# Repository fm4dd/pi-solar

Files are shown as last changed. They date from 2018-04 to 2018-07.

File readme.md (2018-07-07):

# Pi-Solar

Pi-Solar is a solar power generation project for the Raspberry Pi weather station <a href="https://github.com/fm4dd/pi-weather">Pi-Weather</a>, with the goal to achieve independent and longterm "off-the-grid" operation. This project documents the system design and the solar power generation monitoring software that watches over the electrical energy balance.

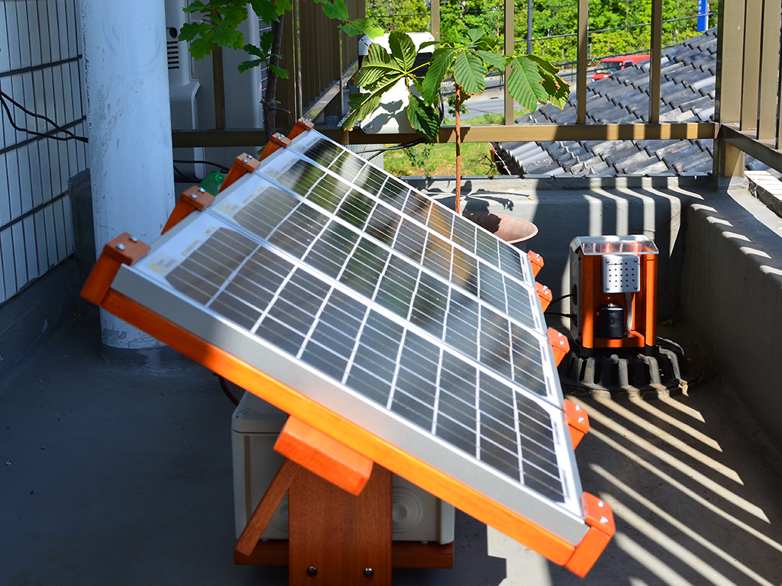
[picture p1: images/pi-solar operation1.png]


The solar power generator after construction, during the initial burn-in trials.

## Live Power Status

http://weather.fm4dd.com/pi-ws01/solar.php

## Design

The solar panel array has four 10W Autumn Technology AT-MA10A pv panels, connected via Victron BlueSolar MPPT 75/10 charge controller to a Yuasa NPH12-12 deep-cycle battery.  The solar panel array angle can be adjusted up to approx 48 degrees.

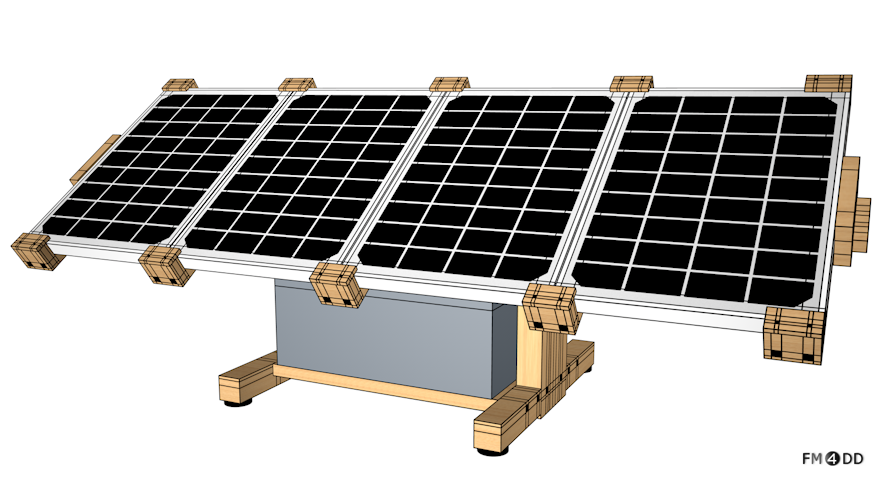
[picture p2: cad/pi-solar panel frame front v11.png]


Battery and charge controller are placed in a OBO T350 junction box enclosure below the panel array. There is space for a second battery to enhance the capacity and increase the bad weather safety margin. 

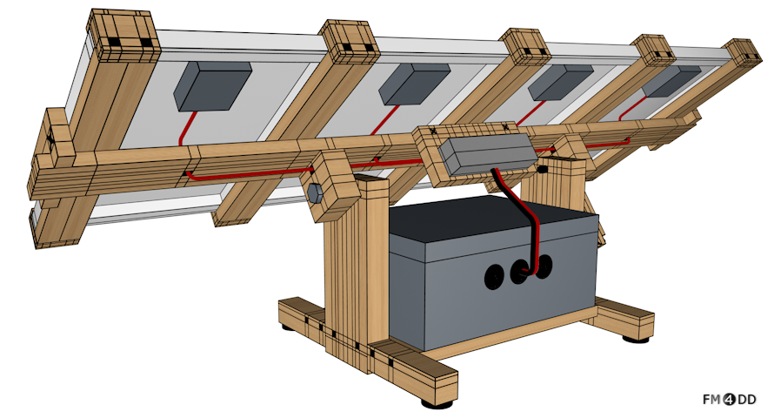
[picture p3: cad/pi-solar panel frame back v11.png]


## Charge Controller monitoring software

The charge controller selection zeroed in on Victron's BlueSolar and SmartSolar series. The selection criteria besides panel power match-up are compact size, ruggedness, and a data interface with a open specification. 

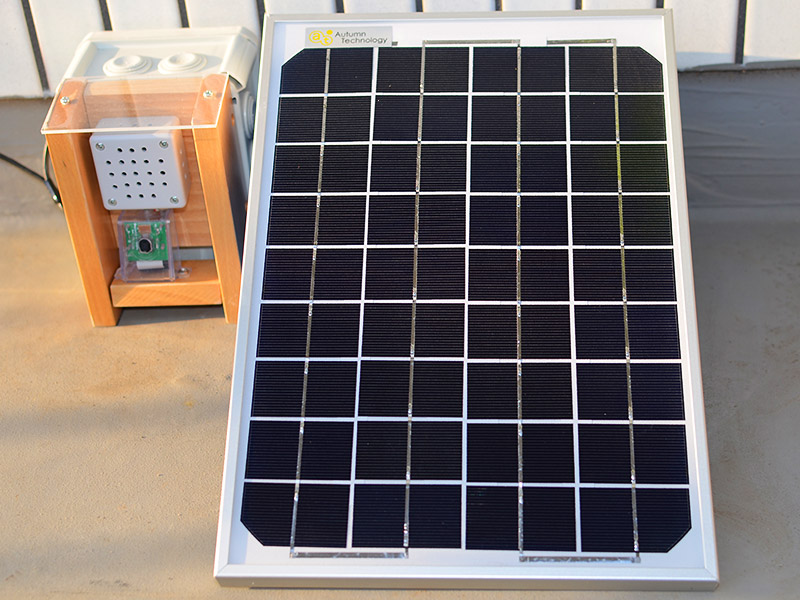
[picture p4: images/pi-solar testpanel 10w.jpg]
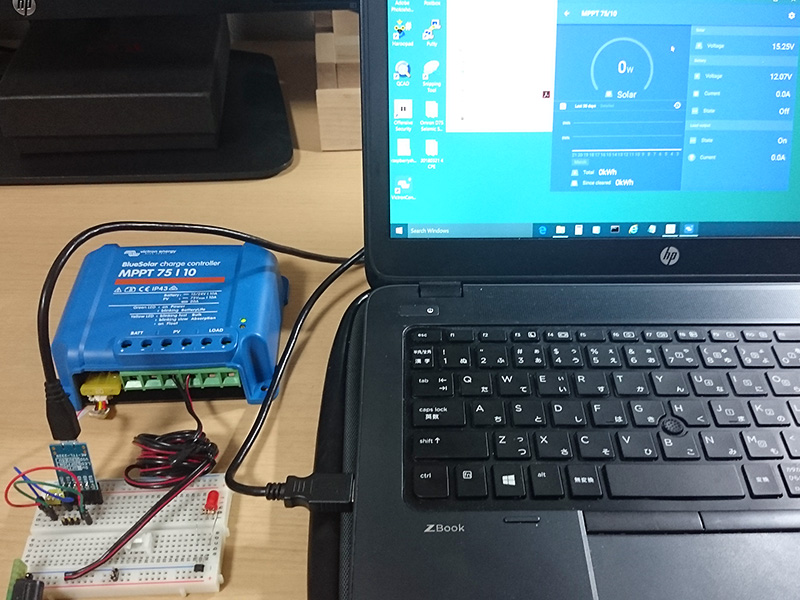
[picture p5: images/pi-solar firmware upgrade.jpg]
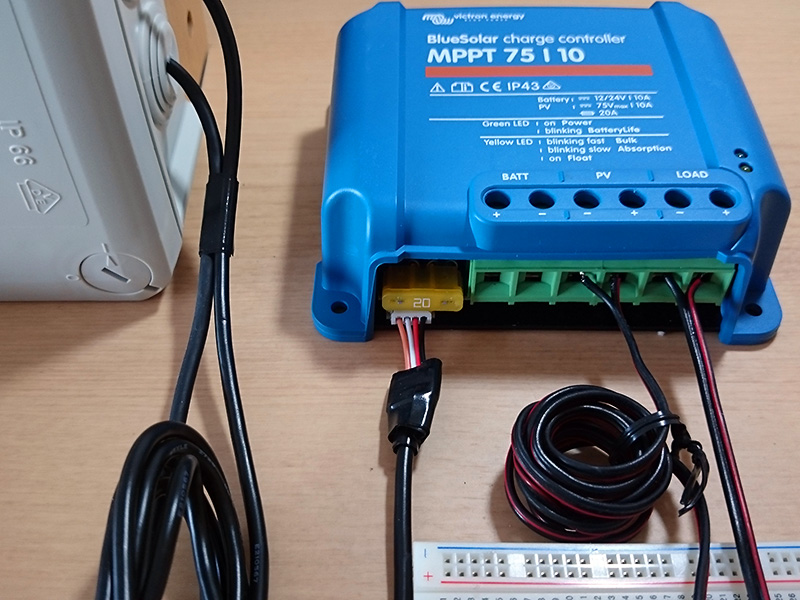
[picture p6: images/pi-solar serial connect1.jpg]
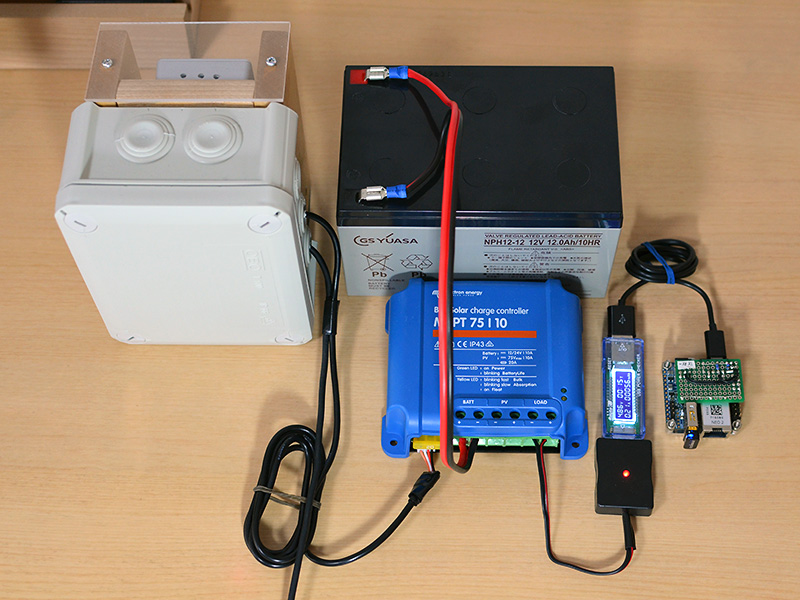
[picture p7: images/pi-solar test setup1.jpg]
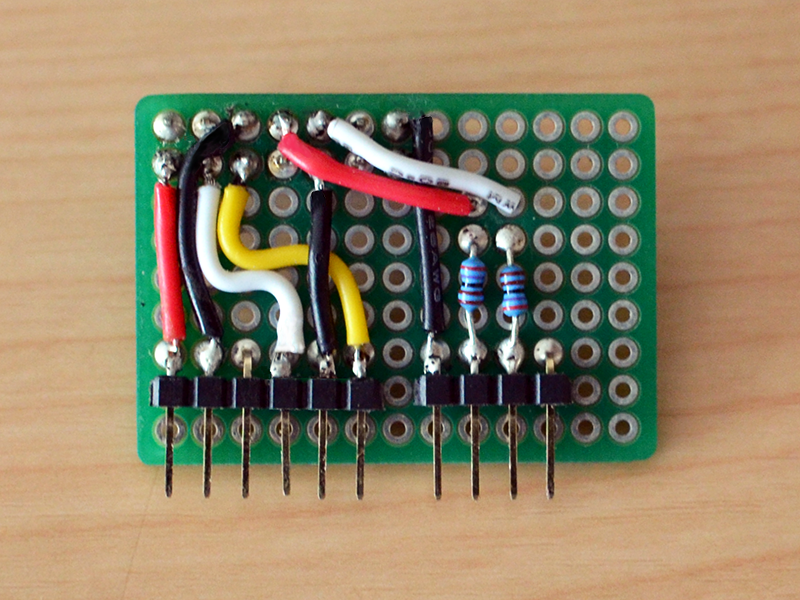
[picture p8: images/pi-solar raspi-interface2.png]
    

The serial line interfacing with a Raspberry Pi worked fine, using a small prototyping circuit board.  Initial software development was mostly done on a NanoPi Neo2 Raspberry clone. The monitoring software was written while powering the controller from a 12V wall plug adapter.  



Charging graph example, showing the panel voltage over 24 hours. The necessary software can be cloned from the <a href="code">code</a> directory.
 
## Solar Panel Array Frame

The <a href="cad">cad</a> directory has the hardware BOM and CAD drawings for panel frame manufacture, and lists the required components. Design goals for the frame are ruggedness, panel tilt adjustment, wood material, assembly/dissassembly options, and portable parts with a size not exceeding 60 cm length.

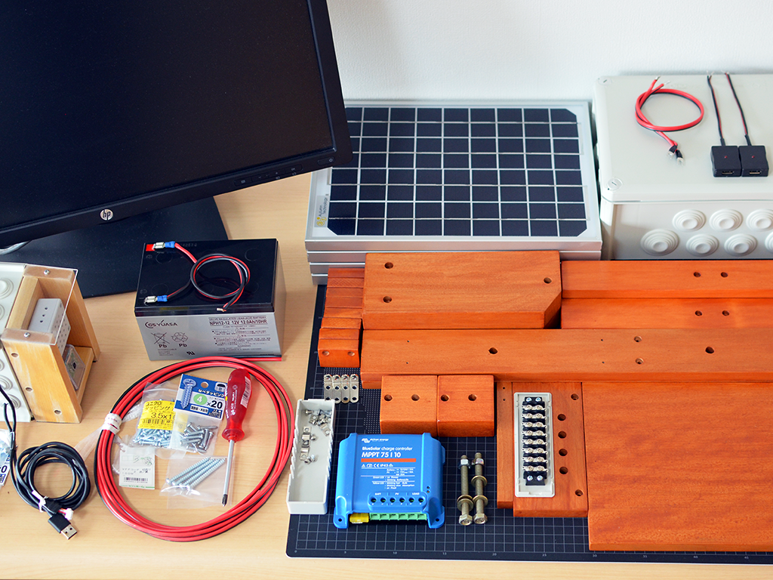
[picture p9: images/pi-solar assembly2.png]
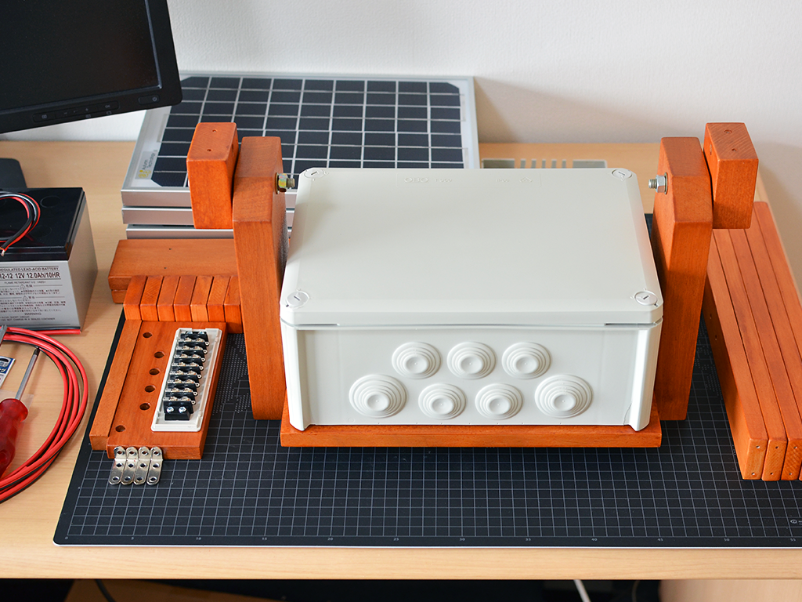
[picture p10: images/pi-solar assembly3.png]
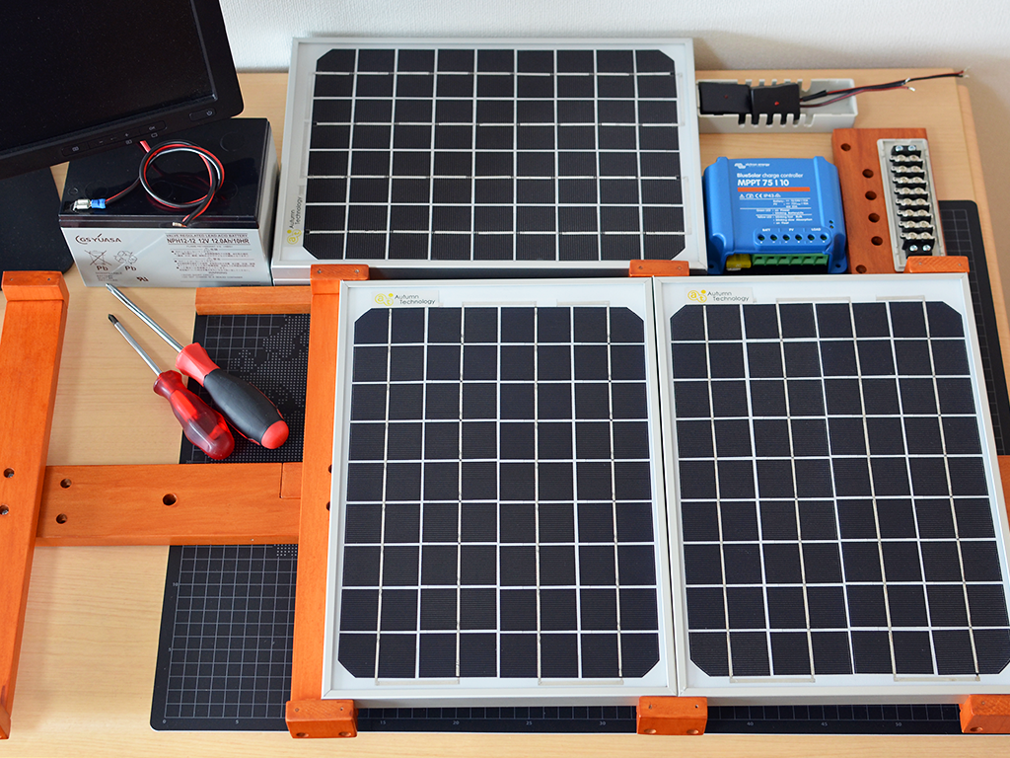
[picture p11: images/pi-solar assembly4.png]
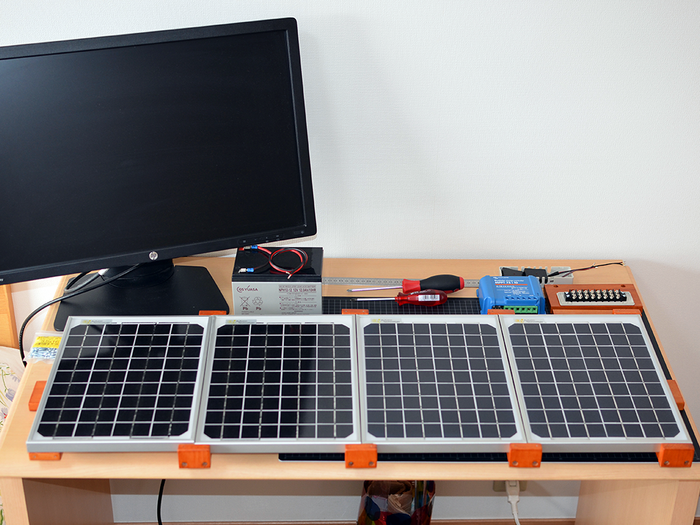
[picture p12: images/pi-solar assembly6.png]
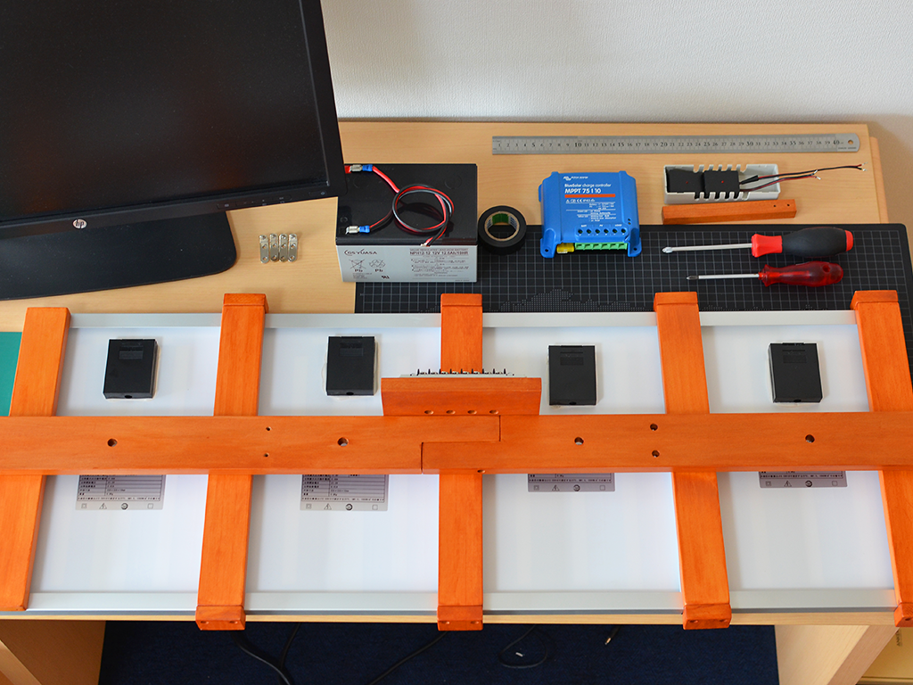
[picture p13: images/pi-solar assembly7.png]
    

Panel fitting and wire routing:

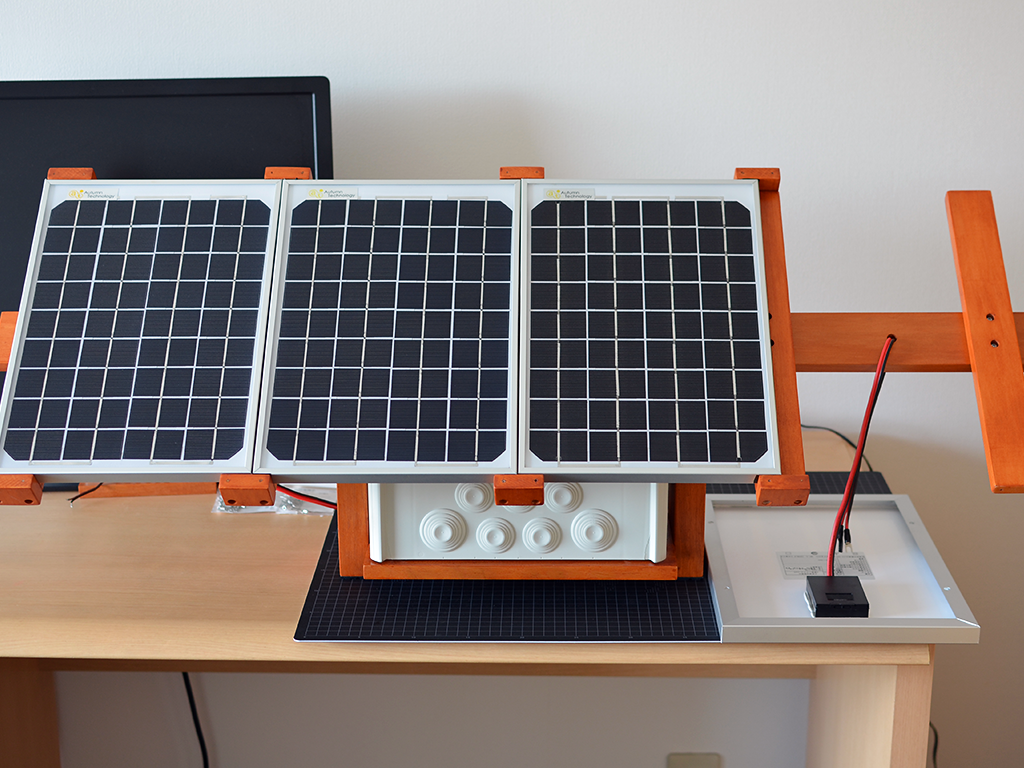
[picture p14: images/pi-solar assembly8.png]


The solar panel wiring has been upgraded to 2mm copper wire of equal length, and a 10A10 rectifier bypass diode has been installed.

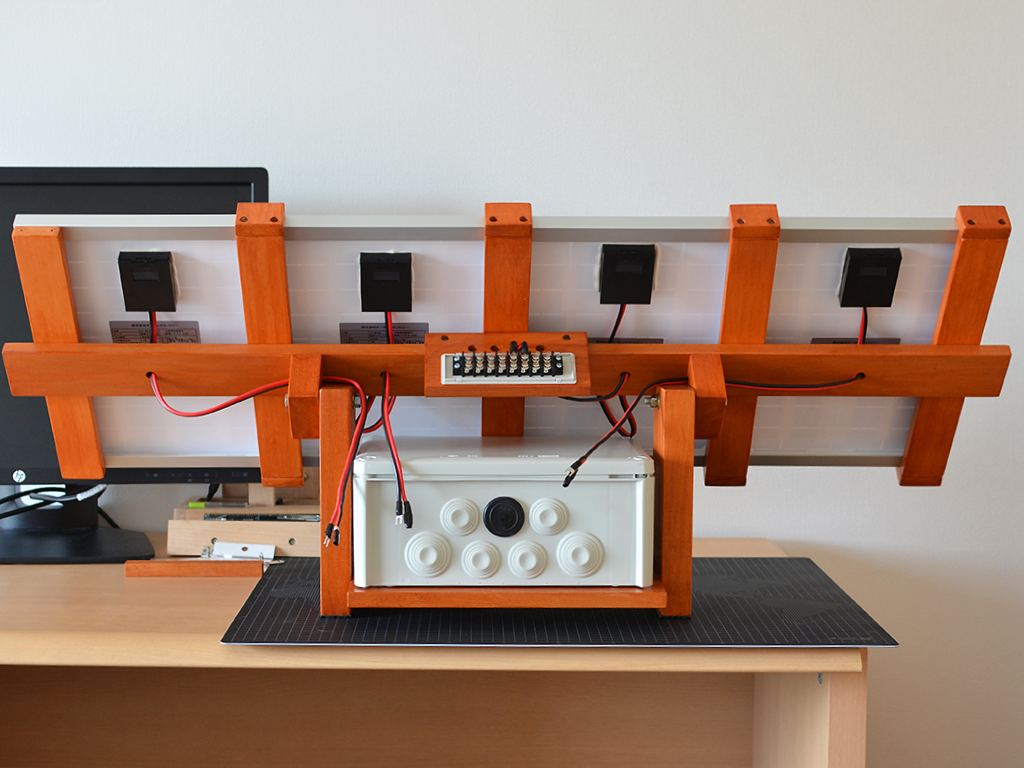
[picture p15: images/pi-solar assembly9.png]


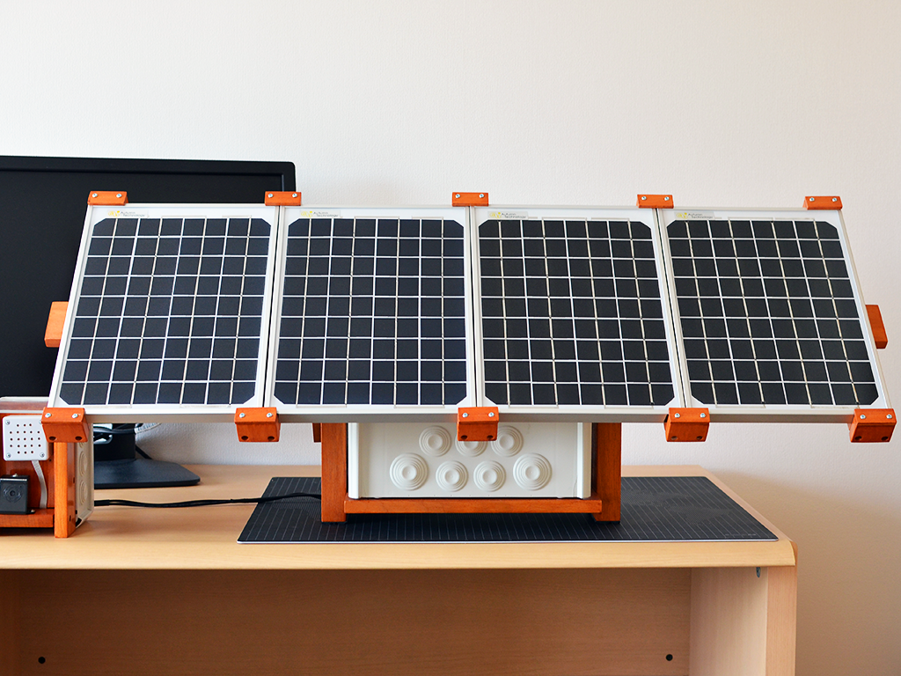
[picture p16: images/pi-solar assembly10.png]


The completed frame after assembly. The stand turned out to be insufficiently stable due to the panel weight with a high center of gravity. Four stabilizers (not pictured here) were added afterwards to sufficiently counter the weight and prevent tipping in high wind situations.

## Power observations

Initial power trials with three panels (30W) showed the need for greater power "buffer" even with a MPPT charger. Poor conditions such as bad weather and obstructive shading reduce the power generation to near zero, and need to be compensated with charging as fast as possible when conditions are right. The initial solar array frame design, envisioning three panels, was reworked to incorporate one more panel for a total of four.

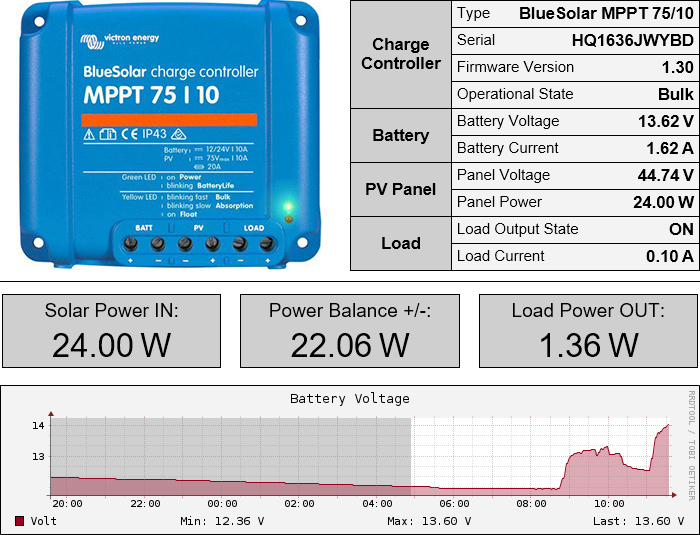
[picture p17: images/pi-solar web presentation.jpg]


3-Panel trials data collection. With panels arranged in series, achieving a higher voltage did not result in better perfomance.

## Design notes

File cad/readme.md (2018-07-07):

# Pi-Solar Design and Build Documentation

This folder contains documentation for the physical build  of a 40W mini solar power generation system. It includes CAD drawings, wiring schemas, bill of materials (BOM) and build pictures.

## PV Panels

Solar power generation comes from four 10W modules, Chinese-build panels from Autumn Technology, model number AT-MA10A.



|Electrical Data|Value |
|---|-|
|Maximum Power|10 W|
|Maximum Operating Voltage|17.5 V|
|Maximum Operating Current|0.57 A|
|Open Circuit Voltage|21.6 V|
|Short Circuit Current|0.62 A|
|Module Efficiency|19.5 %|

|Physical Data|Value|
|---|-|
|External Dimensions|235×335×18mm|
|Module Weight|0.9 Kg|

The panels are build from a string of 36 cell modules, using 2 different cell types: either Bosch, or JA-Solar. Depending on the module type, the panel characteristics are slightly different for operating voltage and current.

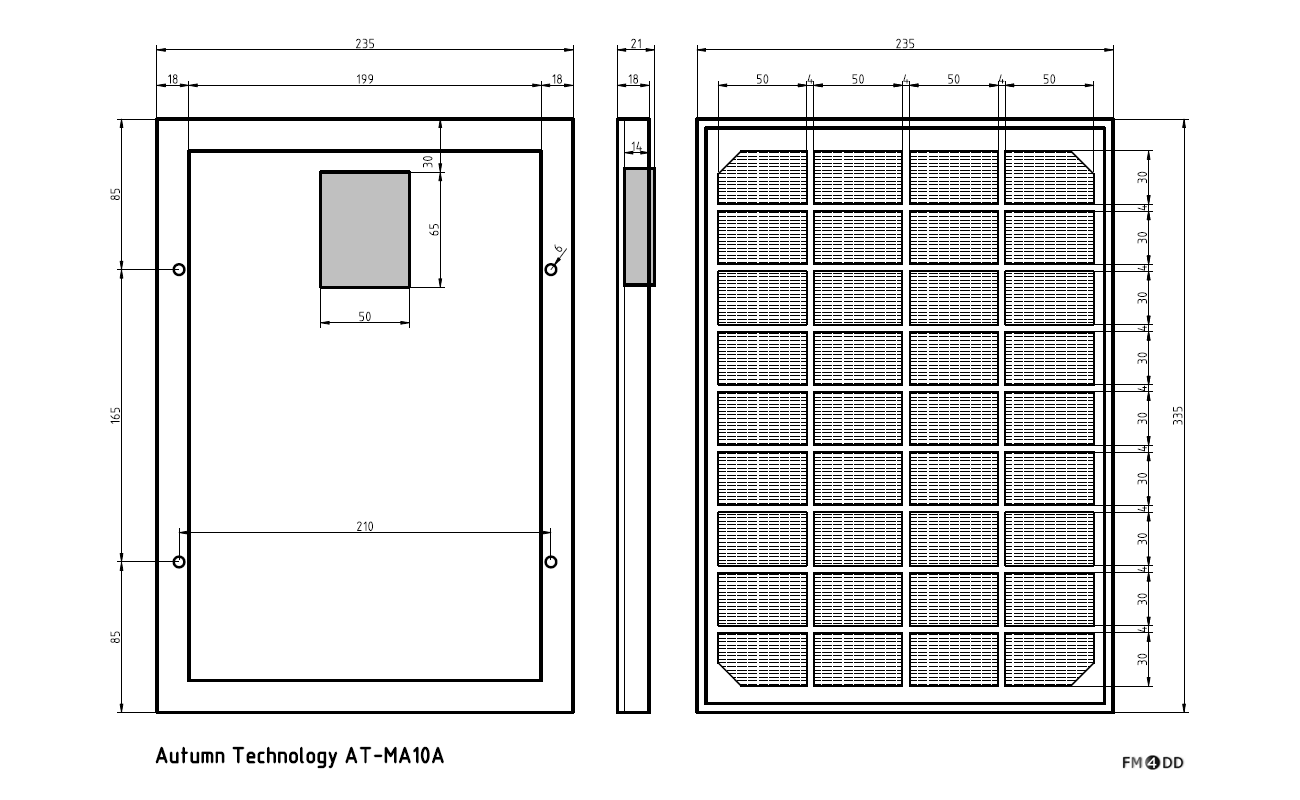
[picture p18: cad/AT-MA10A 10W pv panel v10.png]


##  PV panel carrier frame parts

The PV modules are installed on a carrier frame, which also holds the electrical components including cable terminal, deep-cycle battery, charge controller, and voltage converter. The PV panel holder is mounted with tilt angle adjustment.

###  Side pillars A-B

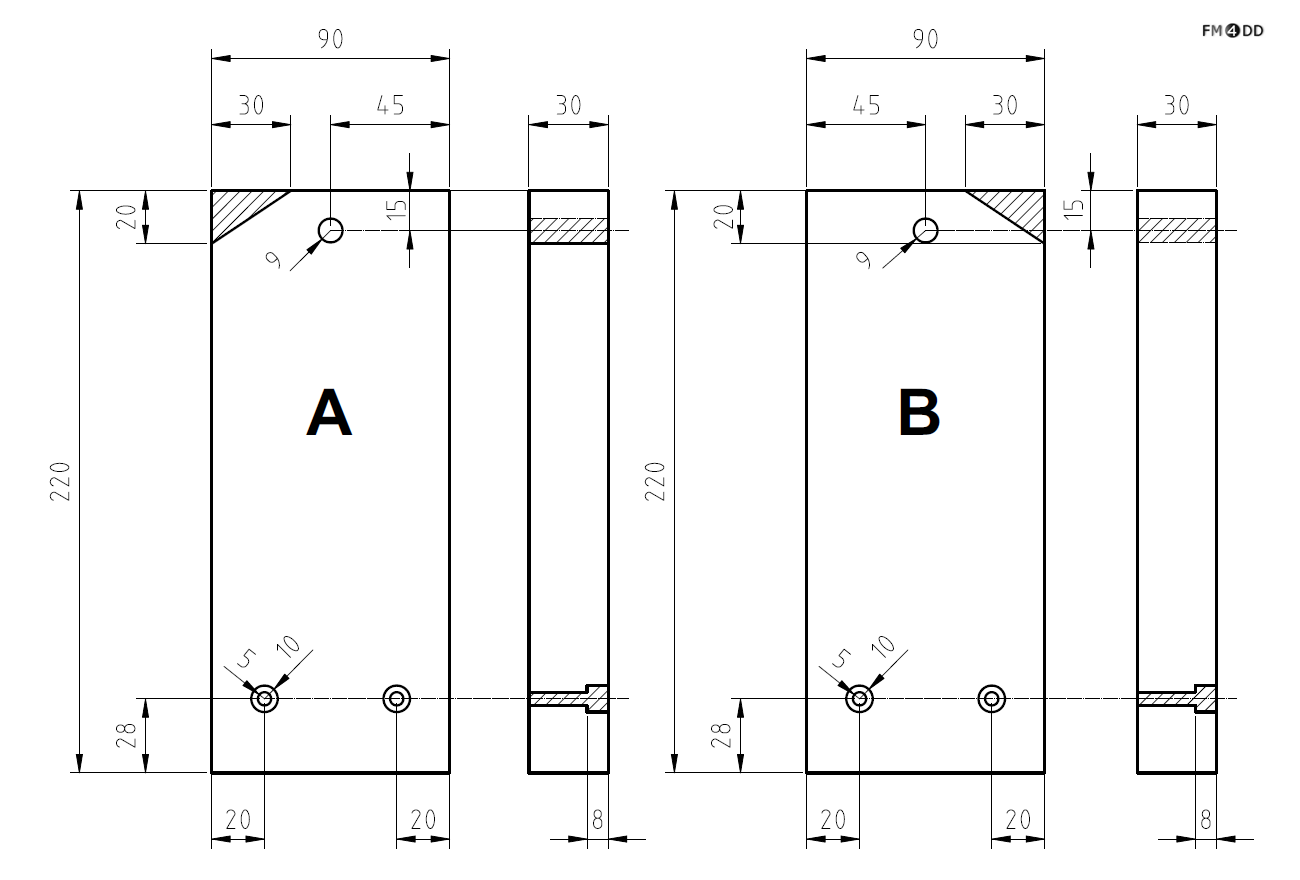
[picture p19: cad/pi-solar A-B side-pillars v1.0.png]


Side pillars A-B (left,right) fix a 300x200 panel 20mm above ground. The bottom panel holds the OBO T350 junction box containing electrical components.

###  Pivot Blocks C-D

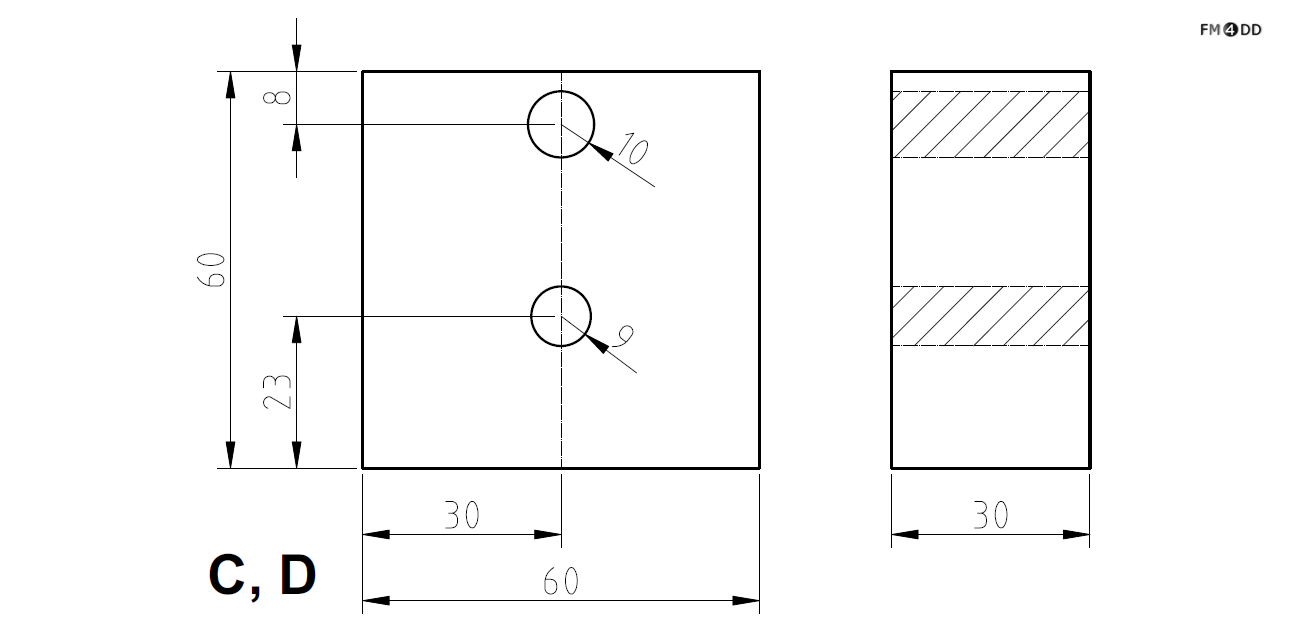
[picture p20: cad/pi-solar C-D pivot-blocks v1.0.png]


Pivot blocks attach the PV panel holder to the side pillars.

###  Main Bars E-F

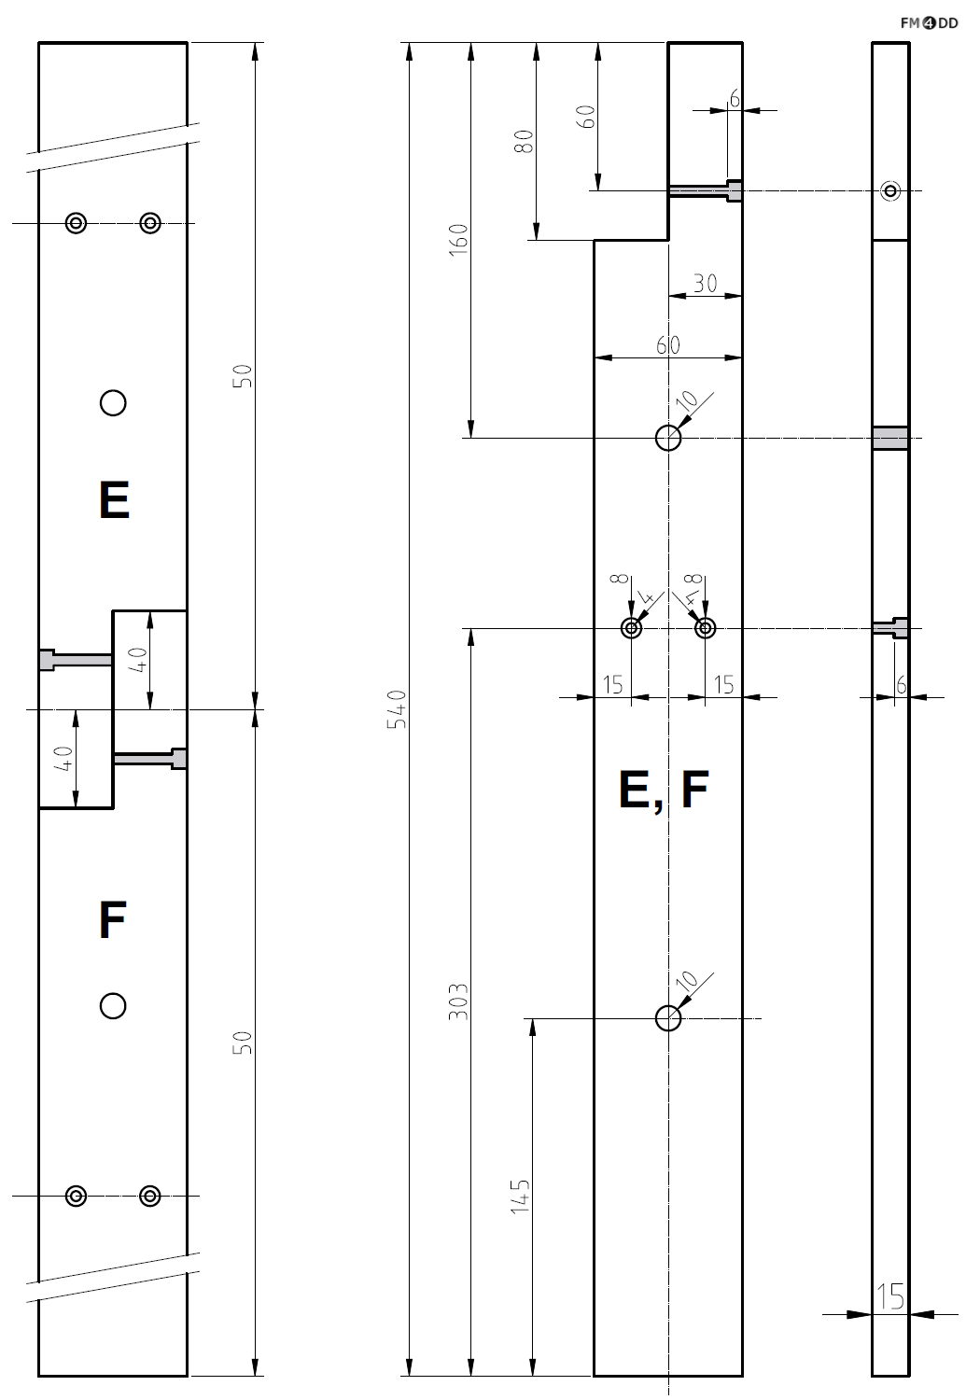
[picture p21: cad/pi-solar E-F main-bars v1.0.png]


The main bars provide the horizontal fixation over the PV panel group, connecting to the pivot blocks and fixate the PV panel vertical fixation bars. The main bar is assembled from two parts to reduce the overall length of a single part.

###  Vertical Bars G-K, Vertical End L-U

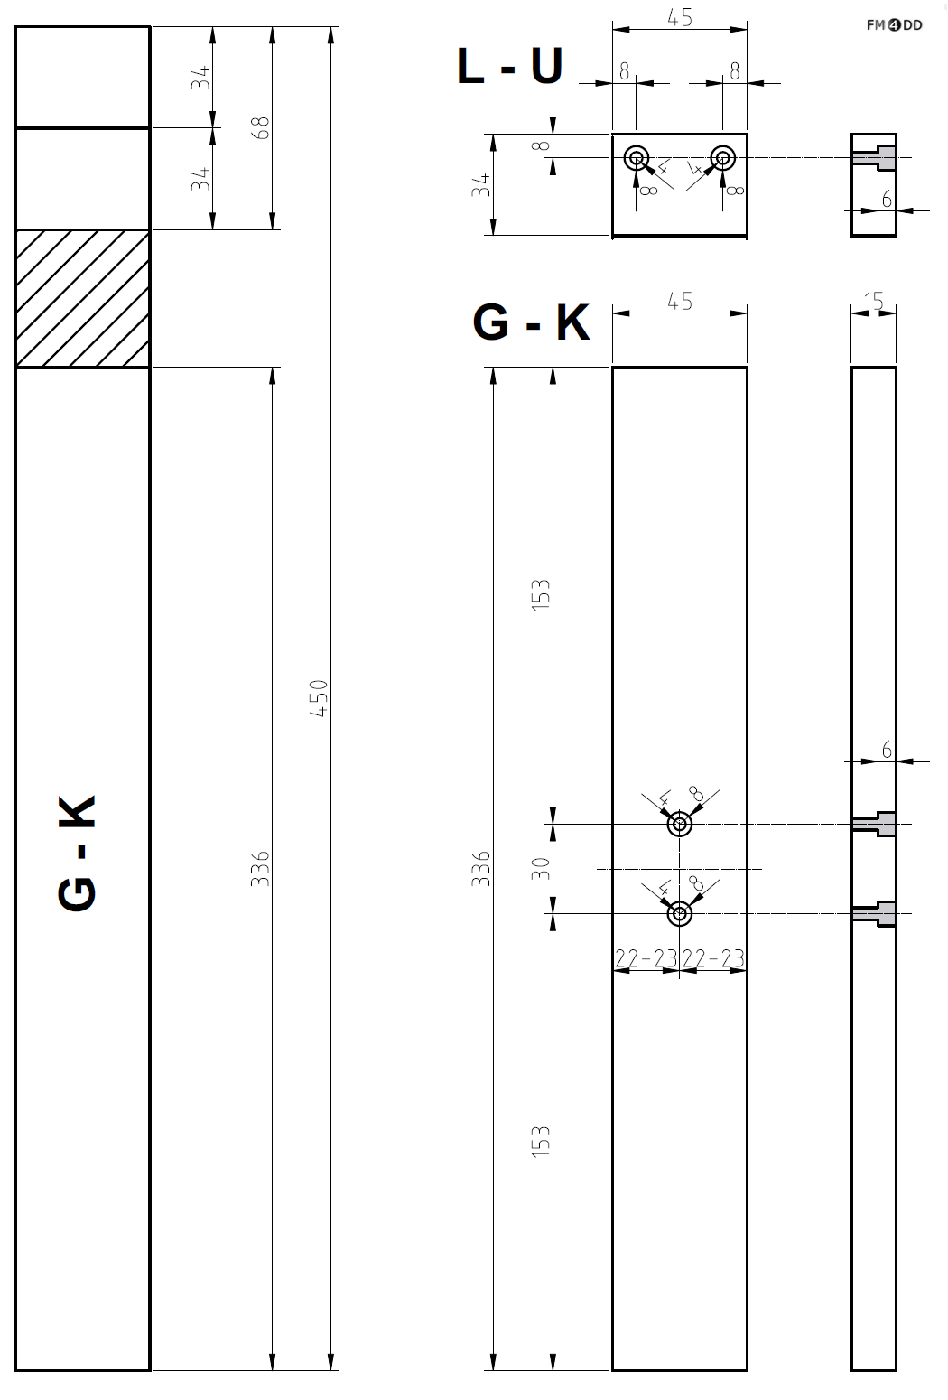
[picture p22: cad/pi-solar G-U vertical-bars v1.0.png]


Five vertical bars, cut to the length of a single PV panel frame. Remaining material is used for the ten vertical bar end pieces on each side.

###  4-panel terminal block V

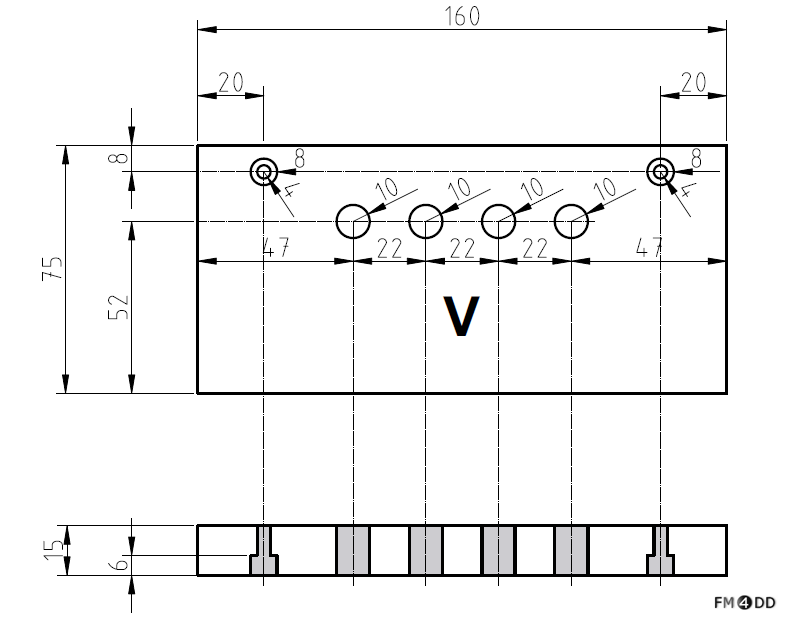
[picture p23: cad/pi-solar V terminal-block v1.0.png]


The terminal block holds the cable terminal which combines the individual PV panels before routing a single cable back to the charge controller in the T350 junction box.

###  Junction box insert W

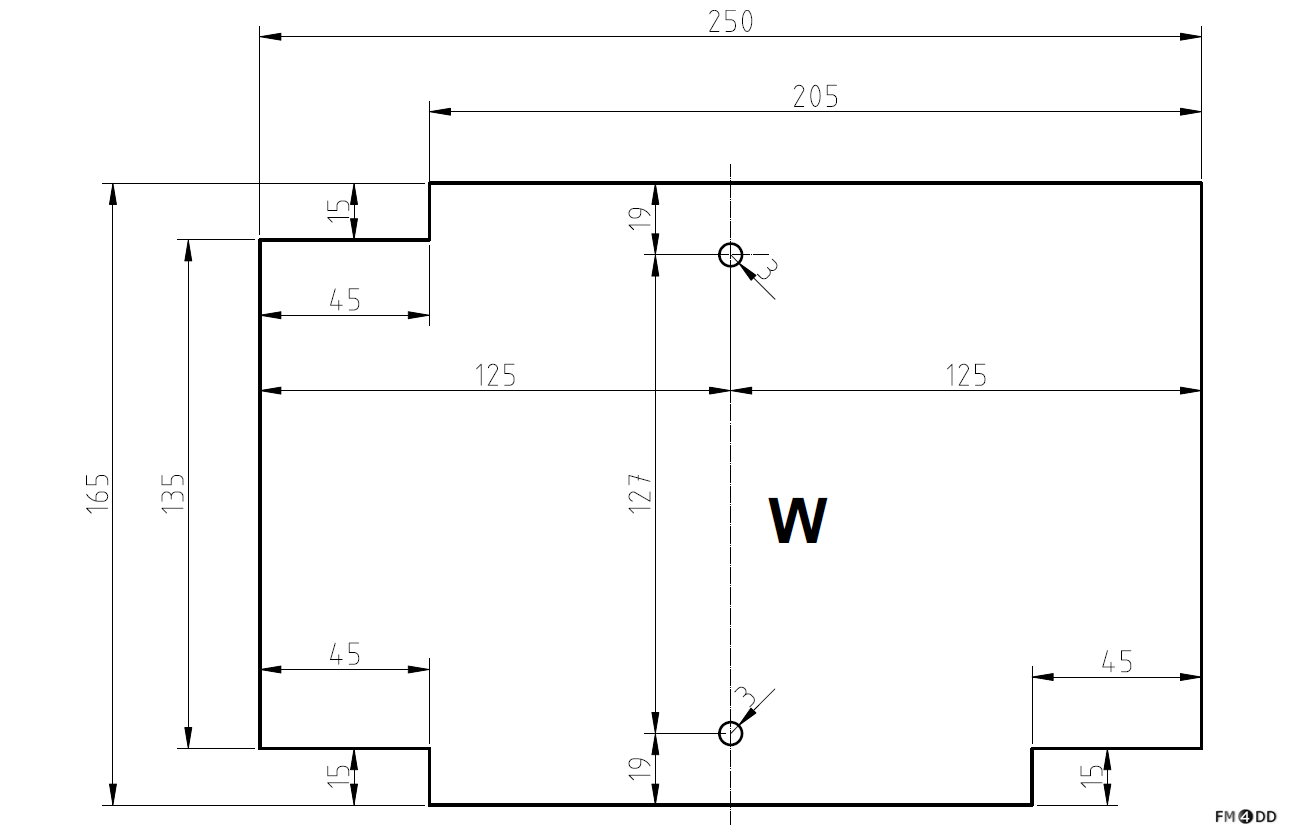
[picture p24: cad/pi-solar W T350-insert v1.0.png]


The junction box insert W is the internal fixation for electrical components inside OBO T350.

### Stabilizer X-Y

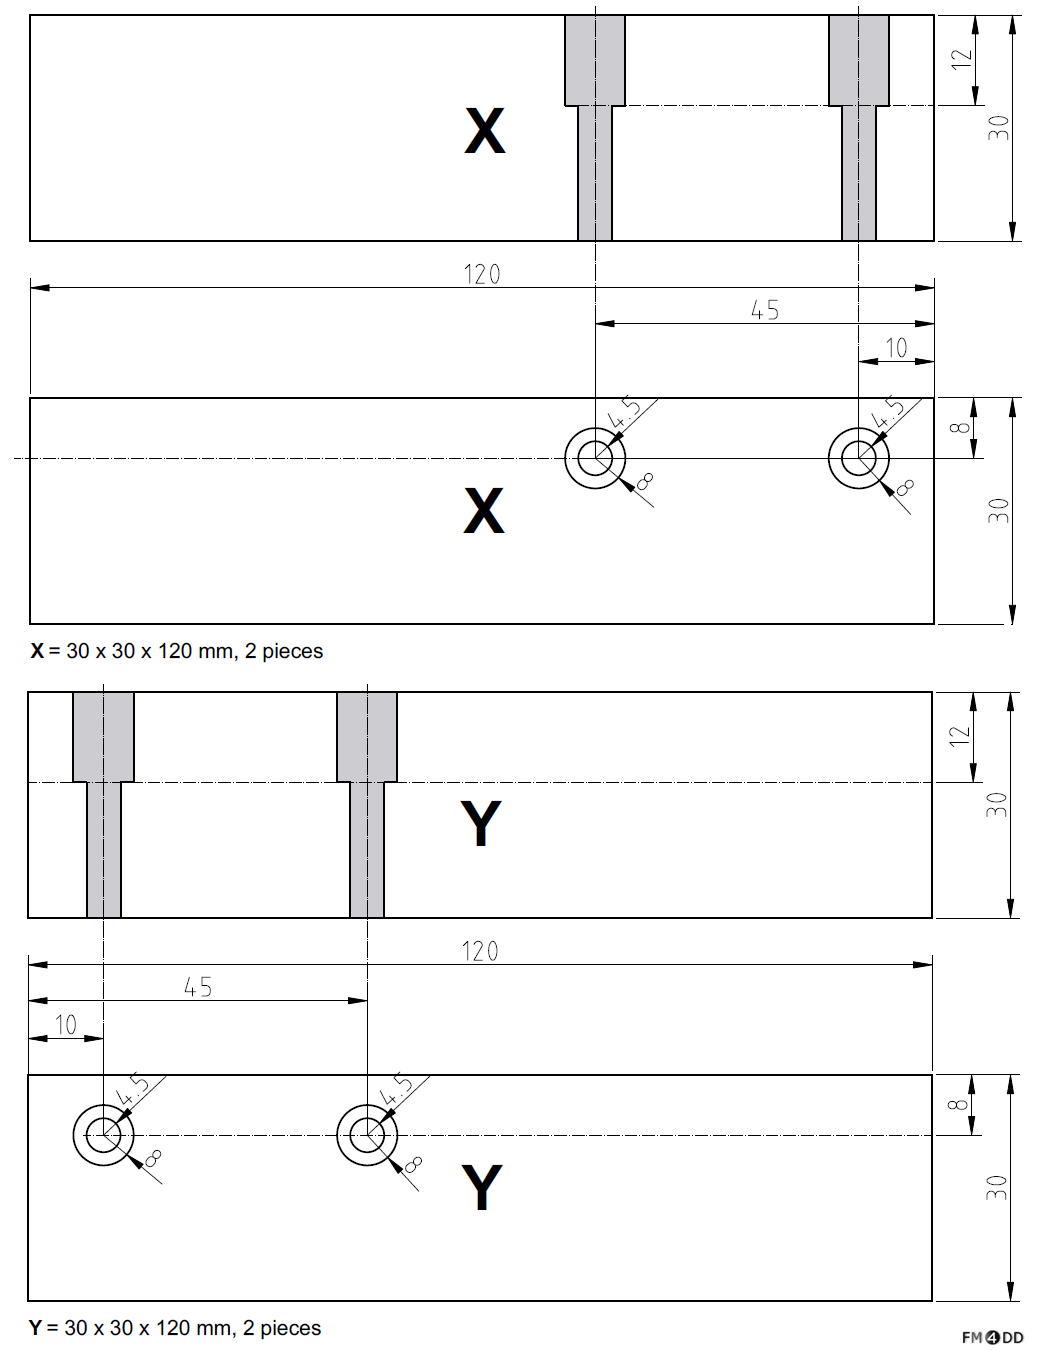
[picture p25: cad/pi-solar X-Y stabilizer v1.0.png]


For stabilizer parts extend the side pillars on four sides to establish a wider footing. They stabilize the PV pannel carrier frame against high winds.

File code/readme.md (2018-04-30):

# Pi-Solar
## Background
The software package **pi-solar** monitors photovoltaic (solar) power generation. I wrote it for size evaluation on a *off-grid* solar system that provides independent power to a outdoor Raspberry Pi weather station. *Off-grid* solar power generation requires a careful design and balance of parameters for uninterrupted, longterm power generation.

Pi-solar likewise can run stand-alone, without connecting to the Internet (except during installation to download approx. 100MB of required software packages). For stand-alone mode, its best to run the Raspberry Pi with a battery-backed real time clock (RTC) to ensure the data readings are always correctly timestamped.

##  Hardware Design
In the current setup, the solar systems electrical data is generated by a <a href="https://www.victronenergy.com/solar-charge-controllers">Victron MPPT solar charge controller</a> from Victron Energy's <a href="https://www.victronenergy.com/upload/documents/Datasheet-BlueSolar-Charge-Controller-overview-EN.pdf">BlueSolar</a> series. In default mode, Victron controllers write a set of 18 parameters in one-second intervals to the serial line interface, as specified in the *ve.direct* protocol. For interfacing a Raspberry Pi with a Victron MPPT charge controller, the wiring diagram is shown below.

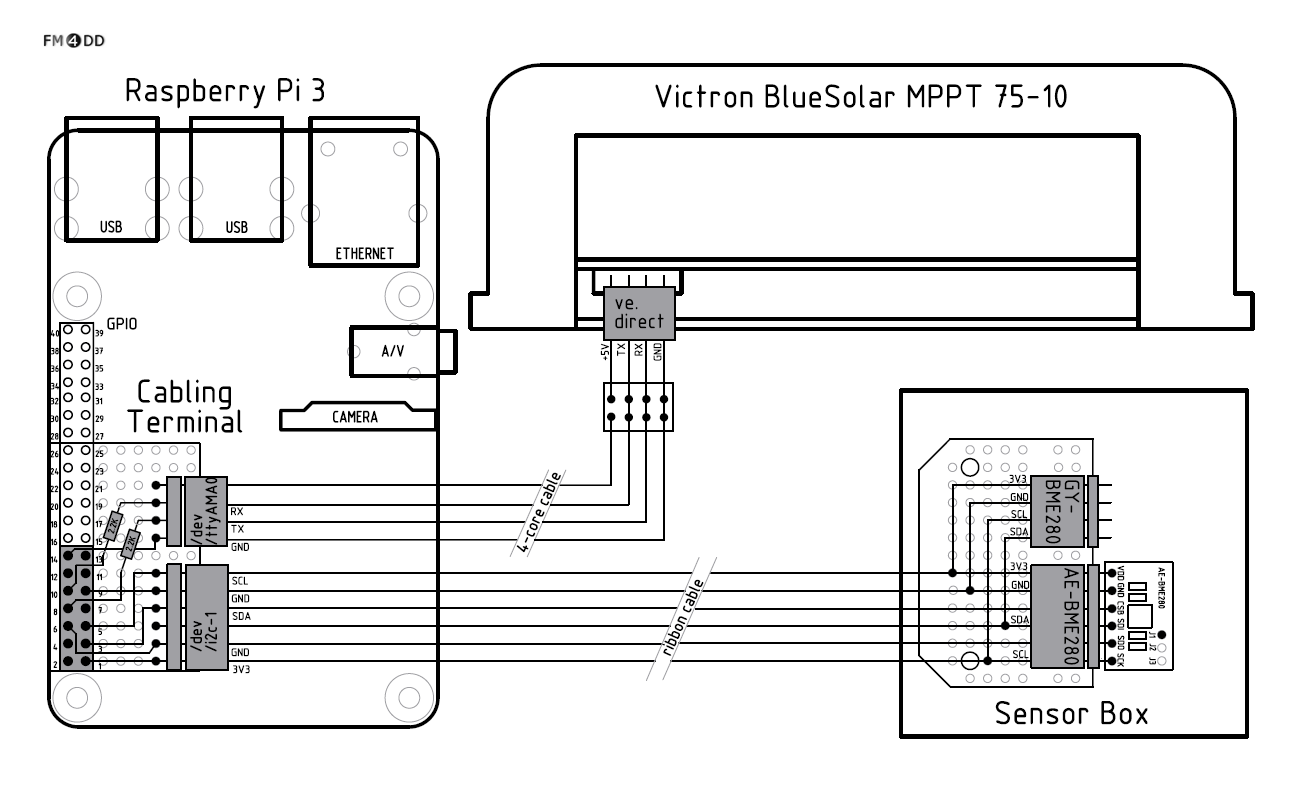
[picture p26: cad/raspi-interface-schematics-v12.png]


## Software Dependencies

Pi-solar runs on a Raspberry Pi under Raspbian Linux 9. It will install a <a href="https://www.lighttpd.net/">lighttpd</a> webserver with PHP as the user interface, and the <a href="http://www.rrdtool.org">RRD</a> packages for the database backend.

System note for Raspberry Pi 3: The more reliable serial interface */dev/ttyAMA0* should be freed up from the Bluetooth interface and routed to the GPIO. This can be achieved by disabling Bluetooth through a device overlay setting in */boot/config.txt*:

`dtoverlay = pi3-disable-bt`

This will swap the serial devices. */dev/serial0* should now point to */dev/ttyAMA0* instead of */dev/ttyS0*:

```
pi@pi-ws03:~ $ ls -l /dev/serial*
lrwxrwxrwx 1 root root 7 Apr 26 19:17 /dev/serial0 -> ttyAMA0
lrwxrwxrwx 1 root root 5 Apr 26 19:17 /dev/serial1 -> ttyS0
```

## Software Installation
After connecting the charge controllers serial port to the Raspberry Pi and downloading this software package, the configuration file *etc/pi-solar.conf* needs to be edited. Then, the script <a href="install/setup.sh">setup.sh</a> in the <a href="install/">install</a> directory makes the necessary system changes. It installs dependend software packages, creates the RRD database *rrd/solar.rrd*, compiles the 'C' programs in <a href="src/">src</a> and creates the cron job entry in */etc/crontab* for data collection.

## Directory Structure

*/home/pi/pi-solar*

| SubDir | Description |
|---|---|
|backup/|Backup files for system-wide crontab and fstab before update by pi-solar|
|bin/|Location for the pi-solar program binaries such as getvictron after compilation|
|etc/|Main configuration file pi-solar.conf, and sftp batch files for Internet upload|
|install/|One-time installation scripts|
|rrd/|RRD database file solar.rrd|
|src/|‘C’ source code and scripts|
|var/|Temporary files. Directory mounted as “Ramdisk” (does not survive reboot)|
|web/|Webserver document home directory (unless integrated with pi-weather package)|

## Software Design
The cron job calls the script <a href="src/solar-data.sh">solar-data.sh</a> in one-minute intervals. This script calls the program <a href="src/getvictron.c">getvictron</a>, which reads the controllers serial data. After capturing the serial line *ve.direct* data record, *getvictron* calculates power values and writes the results into a html code segment before returning the RRD data block which is formatted for updating the RRD database. The script *solar-data.sh* then calls rrdtool update,  which writes the data into the RRD database.

Next, *solar-data.sh* calls <a href="/src/sloar-rrd.sh">solar-rrd.sh</a>, which creates the graph images for data visualization and longterm trending. The graph image files are written into the web server directory and get embedded in a web page, together with the HTML-code segment created by *getvictron*.

Finally, *solar-data.sh* can upload the previously created HTML-code and RRD update string to a Internet server. The Internet server runs a second instance of the RRD database. By running a similar update script, it displays the same data for remote viewing.

One more script exists: <a href="src/solar-night.sh">solar-night.sh</a> uploads a database export each night to the Internet server, if that server is configured. That compensates for any upload outages during the day and re-syncs the server. Its also a basic form of database "backup".

The source code contains two helper programs, <a href="src/daytcalc.c">daytcalc</a> and <a href="src/pvpower.c">pvpower</a>:

*daytcalc* calculates the sunrise and sunset times for a specific place on earth, described by its GPS coordinates. When used with a timestamp, it returns either '0' (day) or '1' (night). This is added as input to the RRD datase, and used to shade the graph images for nighttime/daytime visualization. The calculation should be roughly accurate to a minute.

```
pi@pi-ws03:~/pi-solar/bin $ ./daytcalc -t 1486784589 -x 139.628999 -y 35.610381 -v
Local timezone diff: 32400s (9hrs)
Origin UTCtimestamp: 1486784589
Local calctimestamp: 1486816989
Local timezone date: Sat Feb 11 12:43:09 2017
The day of the year: 42

Local sunrise:  6:33 sunset: 17:19
Local sunrise: Sat Feb 11 06:33:00 2017
Local  sunset: Sat Feb 11 17:19:00 2017
Daylight time: 10:46
Calc TS: 1486816989 SunriseTS: 1486794780 SunsetTS: 1486833540
RRD return value: 0 (day)
```

A RRD graph example with nighttime shading applied:



*pvpower* queries the RRD database, but instead of creating a graph it creates a summary table.  It runs through the data set of a given period and writes the daily power generation and energy balance values as a HTML table segment file, e.g. *daypower.htm*. *pvpower* is called from *solar-rrd.sh*.



## Demonstration URL

The software and current solar power generation data can be seen live at <a href="http://weather.fm4dd.com/pi-ws03/solar.php">http://weather.fm4dd.com/pi-ws03/solar.php</a>

Partial static web page content screenshot:


## To-Do List

1. Serial line data capture improvement:

Currently, the serial data capture is not very efficiently done by getvictron. Basically, it records all serial data for two seconds, and then extracts the last complete data record. Although this method seems reliable, it is far from ideal. Instead, we should monitor the serial link, identify and capture the next new data block start record by following the data stream of the link.

2. Deep cycle battery state of charge

Adding the charge level approximation to the Battery voltage graph would give valuable information to identify extensive battery draw.

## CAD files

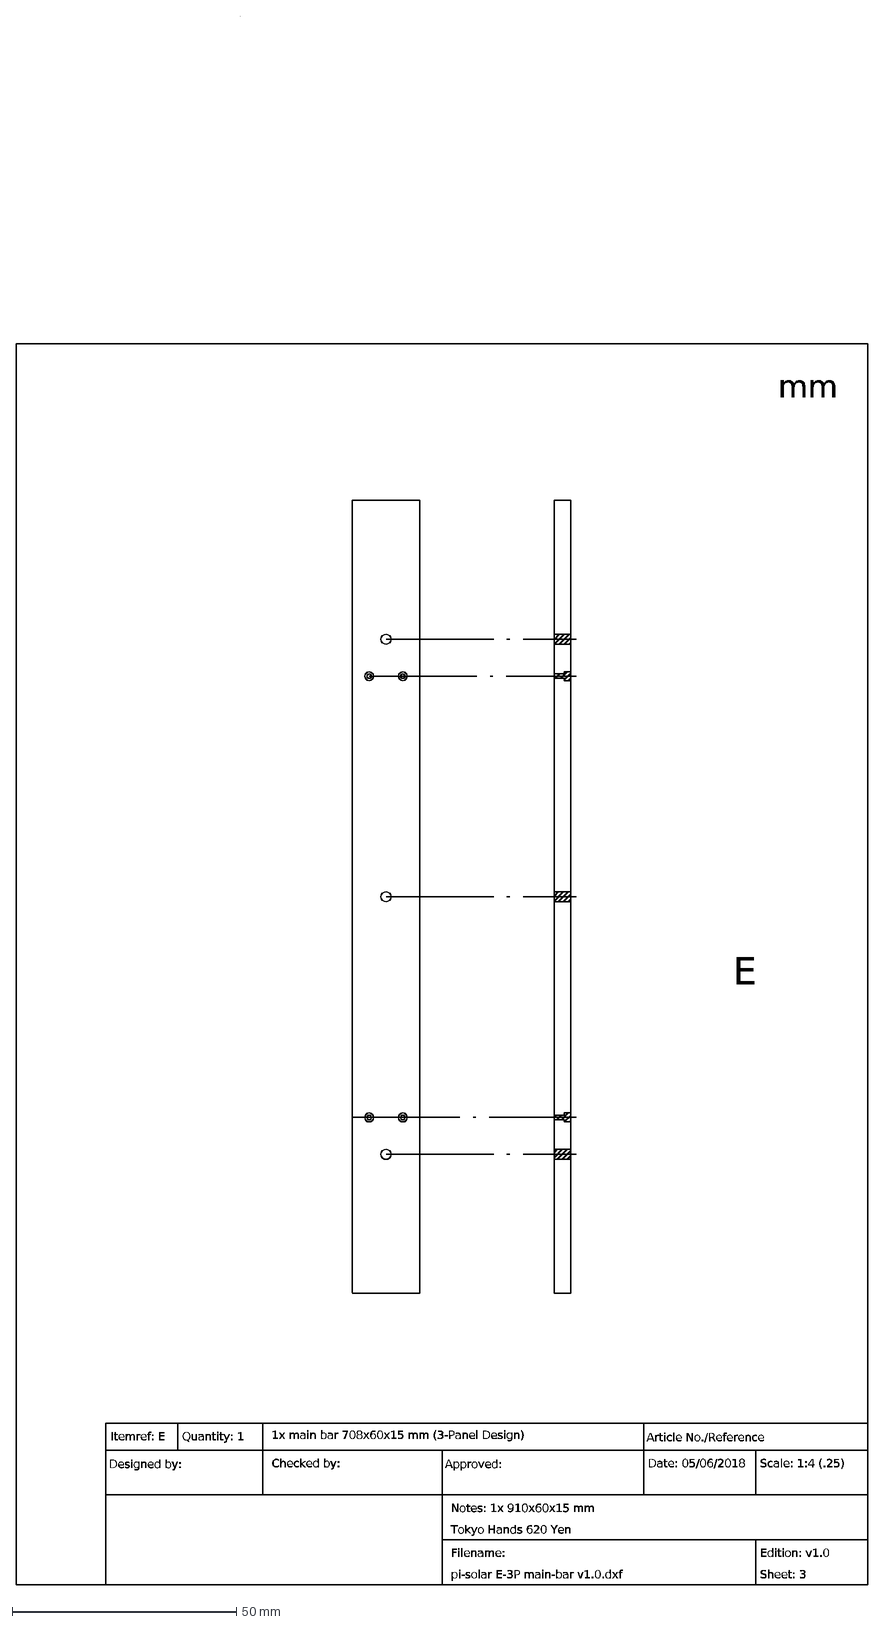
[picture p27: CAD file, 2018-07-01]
cad/pi-solar E-3P main-bar v1.0.dxf
mm
Itemref: E
Quantity: 1
1x main bar 708x60x15 mm (3-Panel Design)
Article No./Reference
Designed by:
Checked by:
Approved:
Filename: pi-solar E-3P main-bar v1.0.dxf
Date: 05/06/2018
Scale: 1:4 (.25)
Edition: v1.0 Sheet: 3
E
Notes: 1x 910x60x15 mm Tokyo Hands 620 Yen

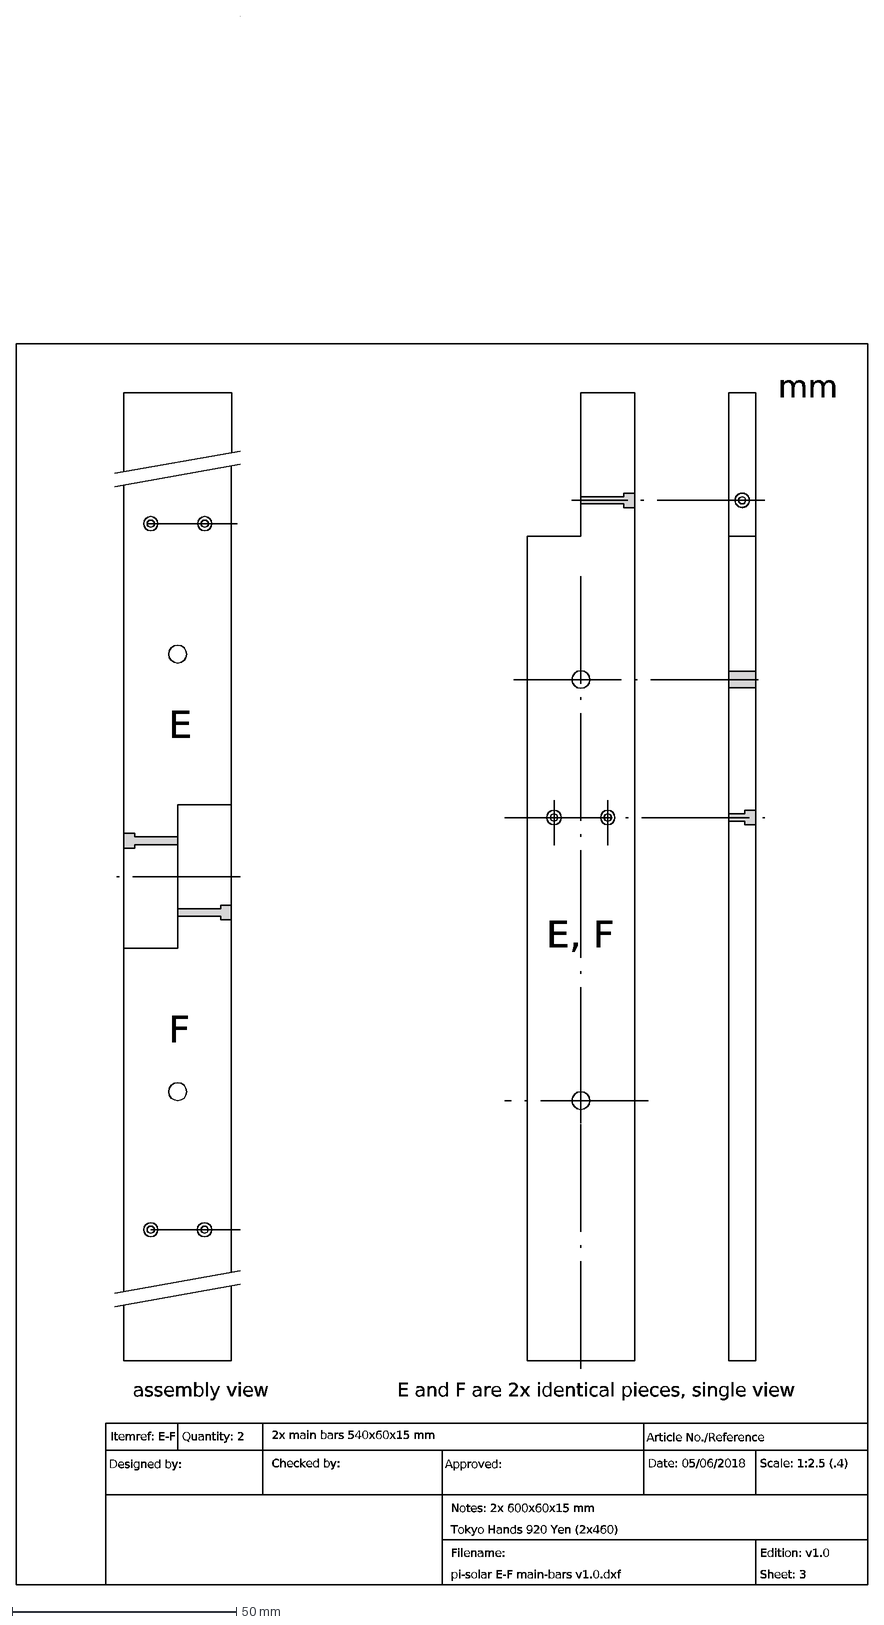
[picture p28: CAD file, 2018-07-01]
cad/pi-solar E-F main-bars v1.0.dxf
mm
E and F are 2x identical pieces, single view
assembly view
Itemref: E-F
Quantity: 2
2x main bars 540x60x15 mm
Article No./Reference
Designed by:
Checked by:
Approved:
Filename: pi-solar E-F main-bars v1.0.dxf
Date: 05/06/2018
Scale: 1:2.5 (.4)
Edition: v1.0 Sheet: 3
E, F
F
E
Notes: 2x 600x60x15 mm Tokyo Hands 920 Yen (2x460)

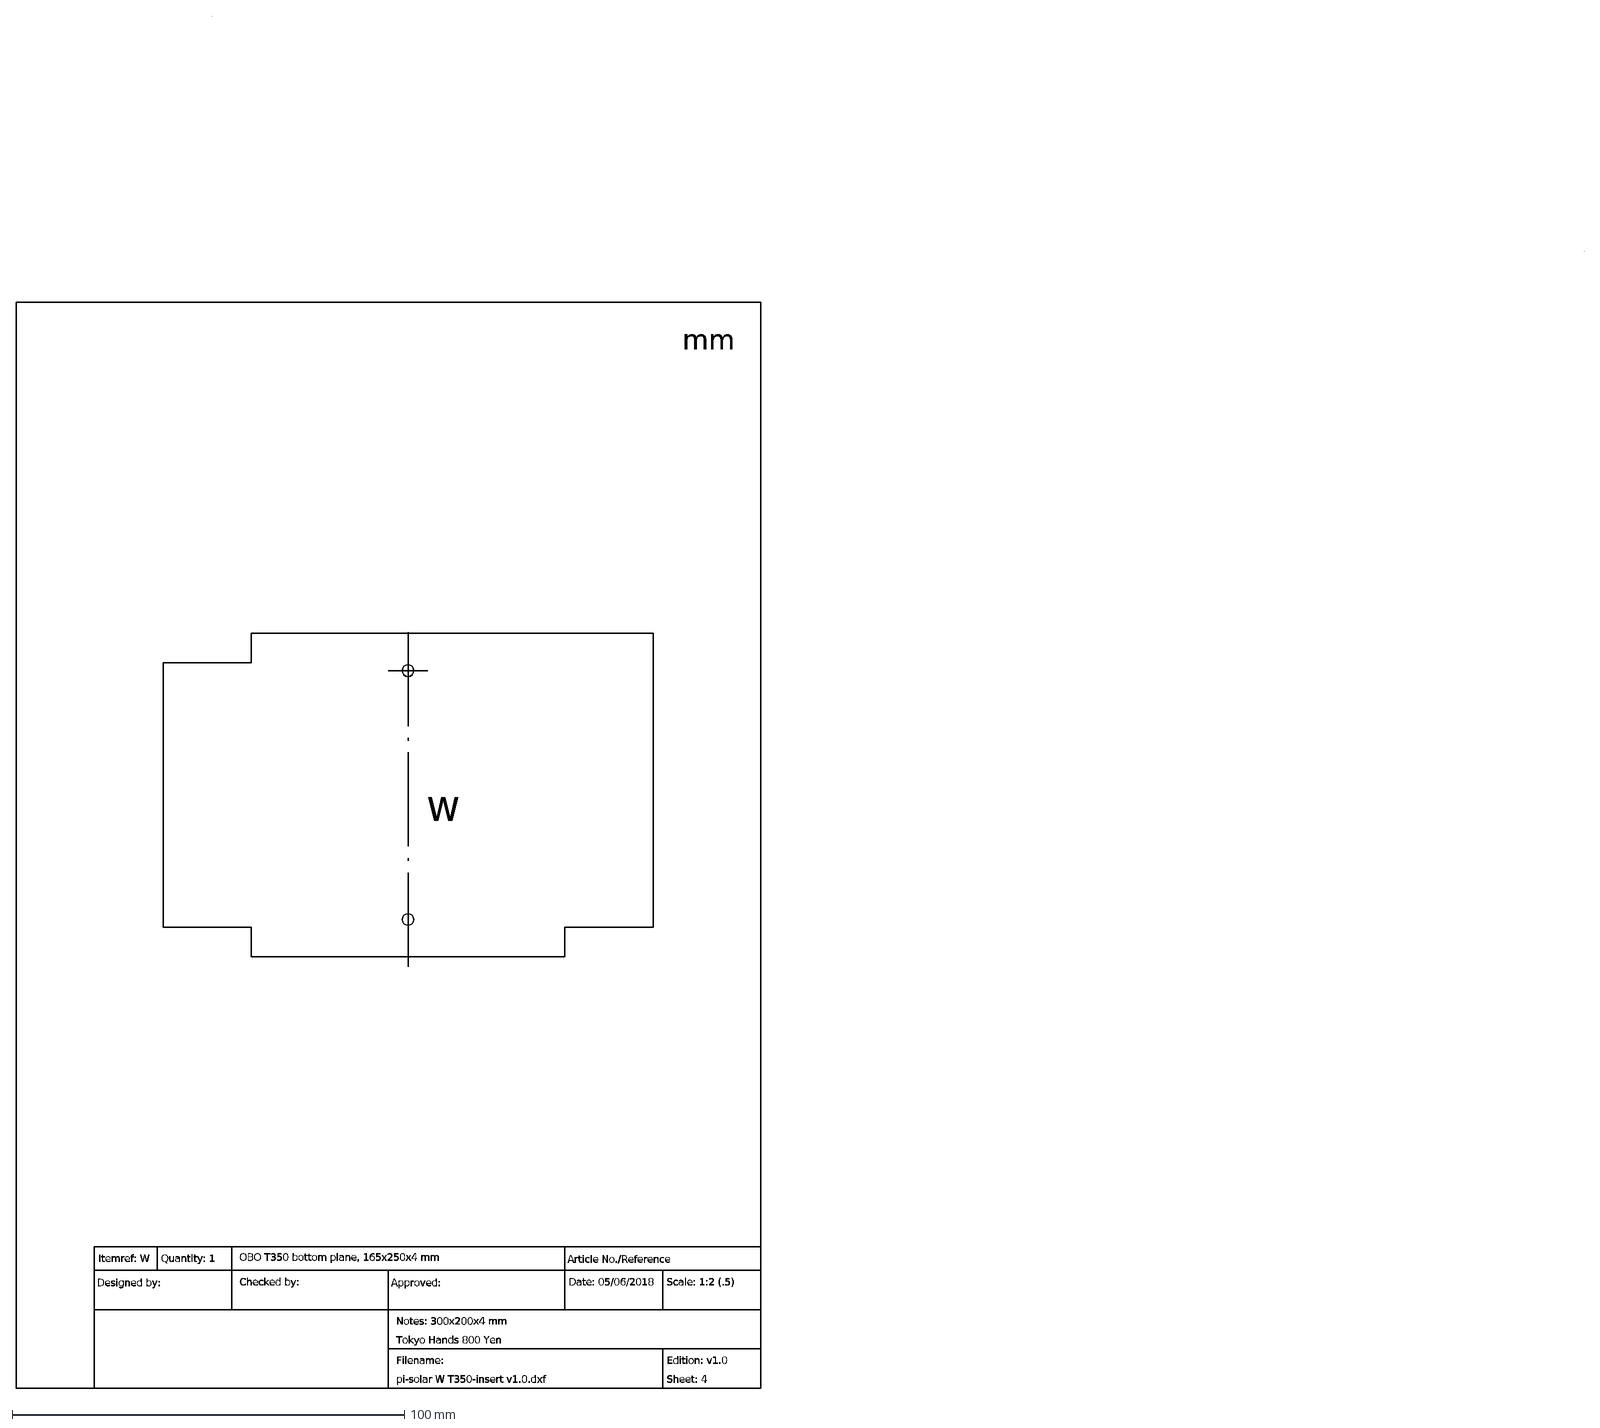
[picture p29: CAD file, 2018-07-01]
cad/pi-solar W T350-insert v1.0.dxf
mm
Itemref: W
Quantity: 1
OBO T350 bottom plane, 165x250x4 mm
Article No./Reference
Designed by:
Checked by:
Approved:
W
Filename: pi-solar W T350-insert v1.0.dxf
Date: 05/06/2018
Scale: 1:2 (.5)
Edition: v1.0 Sheet: 4
Notes: 300x200x4 mm Tokyo Hands 800 Yen

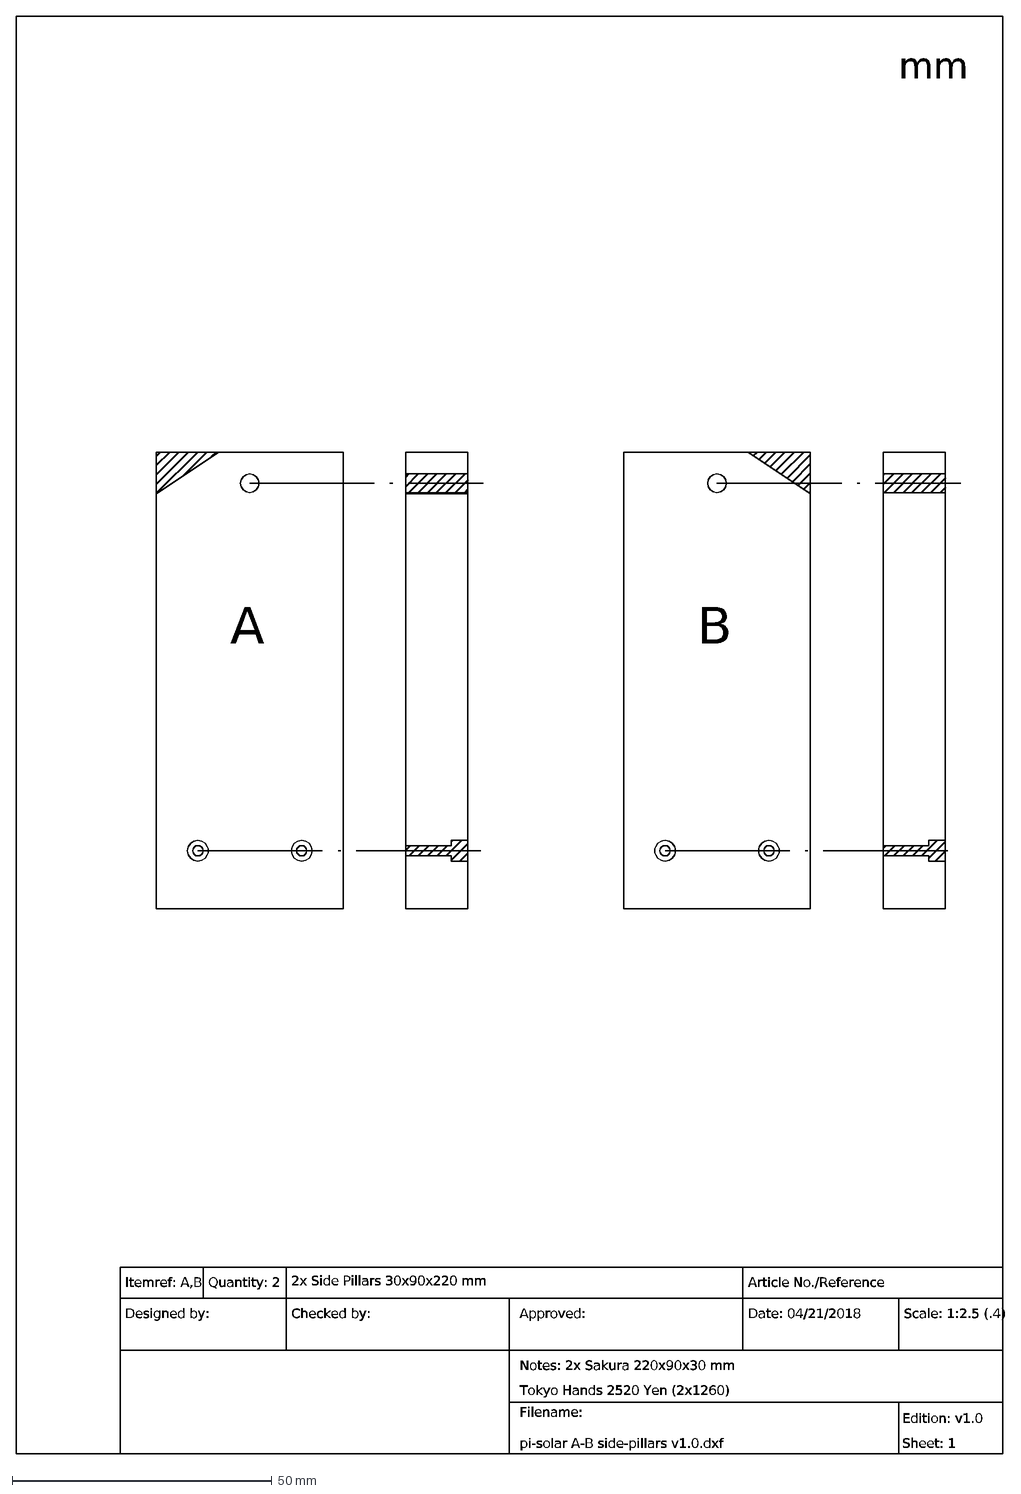
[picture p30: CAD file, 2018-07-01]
cad/pi-solar A-B side-pillars v1.0.dxf
Notes: 2x Sakura 220x90x30 mm Tokyo Hands 2520 Yen (2x1260)
Itemref: A,B
Quantity: 2
mm
A
B
2x Side Pillars 30x90x220 mm
Article No./Reference
Designed by:
Checked by:
Approved:
Filename: pi-solar A-B side-pillars v1.0.dxf
Date: 04/21/2018
Scale: 1:2.5 (.4)
Edition: v1.0 Sheet: 1

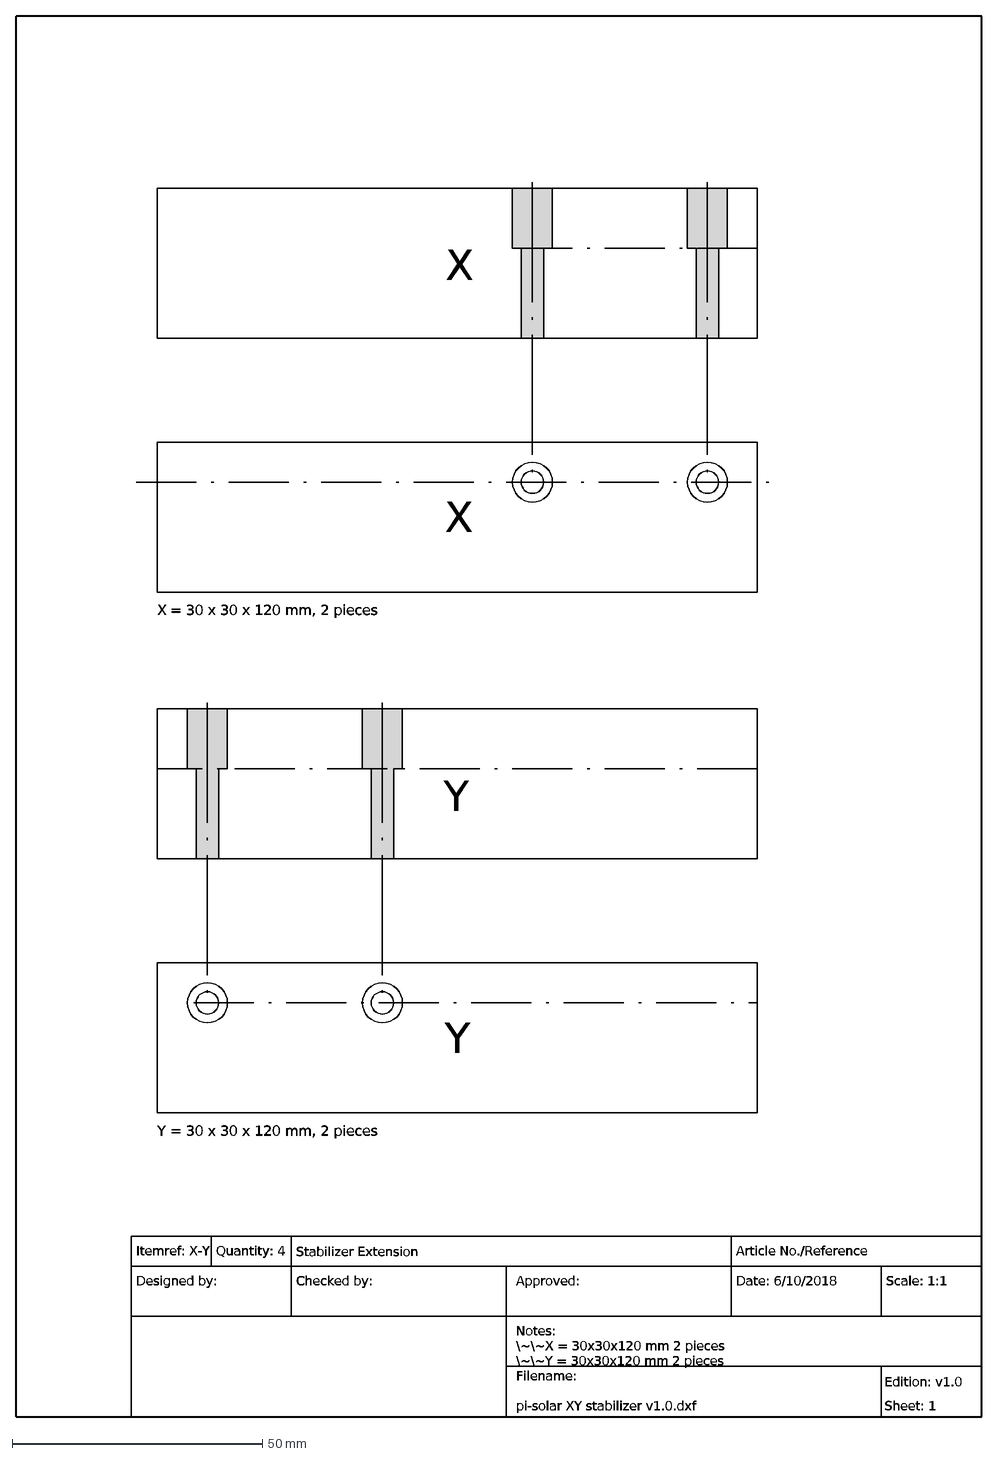
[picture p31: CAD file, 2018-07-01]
cad/pi-solar X-Y stabilizer v1.0.dxf
Notes: \~\~X = 30x30x120 mm 2 pieces \~\~Y = 30x30x120 mm 2 pieces
Itemref: X-Y
X
Y
= 30 x 30 x 120 mm, 2 pieces
Quantity: 4
Article No./Reference
Designed by:
Checked by:
Stabilizer Extension
Approved:
Filename: pi-solar XY stabilizer v1.0.dxf
Date: 6/10/2018
Scale: 1:1
Edition: v1.0 Sheet: 1

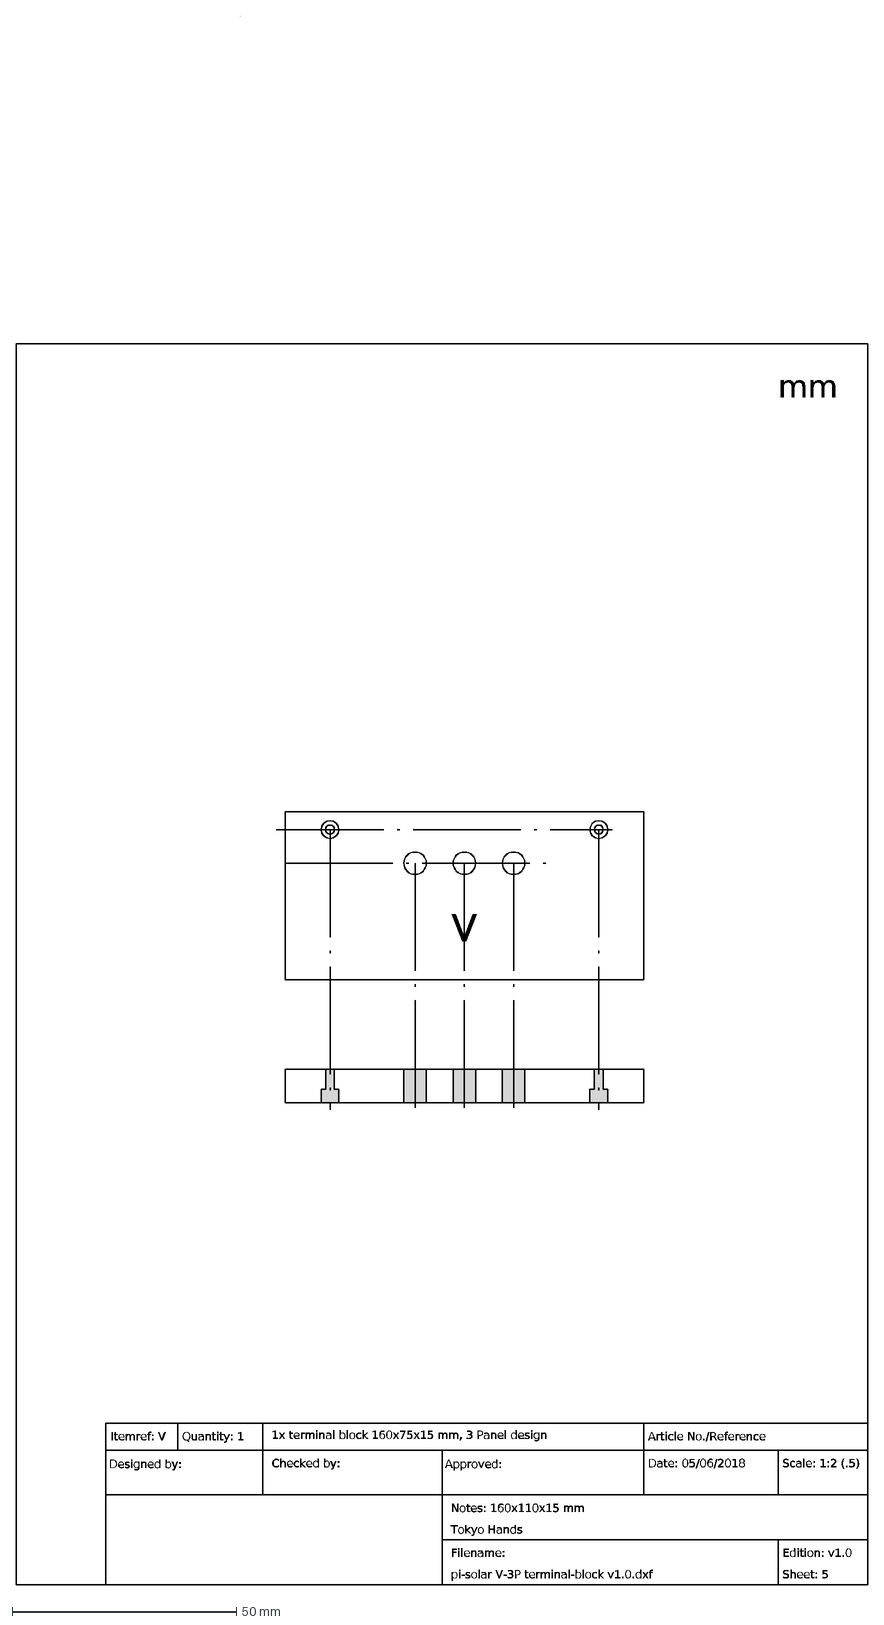
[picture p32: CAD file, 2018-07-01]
cad/pi-solar V-3P terminal-block v1.0.dxf
Itemref: V
Quantity: 1
mm
1x terminal block 160x75x15 mm, 3 Panel design
Article No./Reference
Designed by:
Checked by:
Approved:
Filename: pi-solar V-3P terminal-block v1.0.dxf
Date: 05/06/2018
Scale: 1:2 (.5)
Edition: v1.0 Sheet: 5
Notes: 160x110x15 mm Tokyo Hands
V

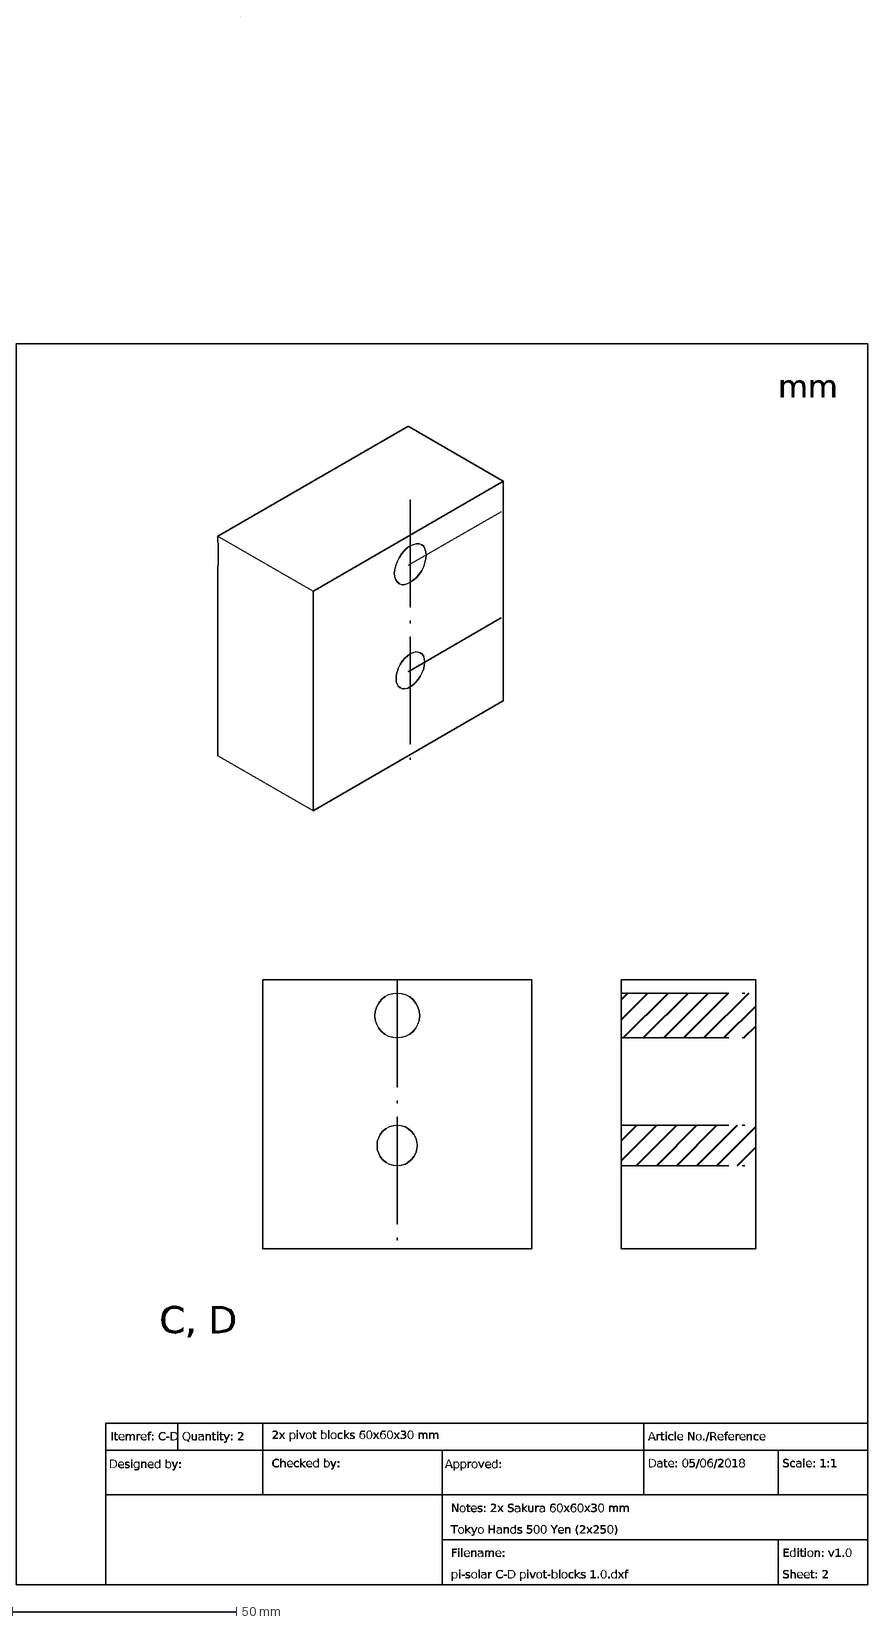
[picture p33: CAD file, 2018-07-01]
cad/pi-solar C-D pivot-blocks v1.0.dxf
Itemref: C-D
Quantity: 2
mm
2x pivot blocks 60x60x30 mm
Article No./Reference
Designed by:
Checked by:
Approved:
Filename: pi-solar C-D pivot-blocks 1.0.dxf
Date: 05/06/2018
Scale: 1:1
Edition: v1.0 Sheet: 2
Notes: 2x Sakura 60x60x30 mm Tokyo Hands 500 Yen (2x250)
C, D

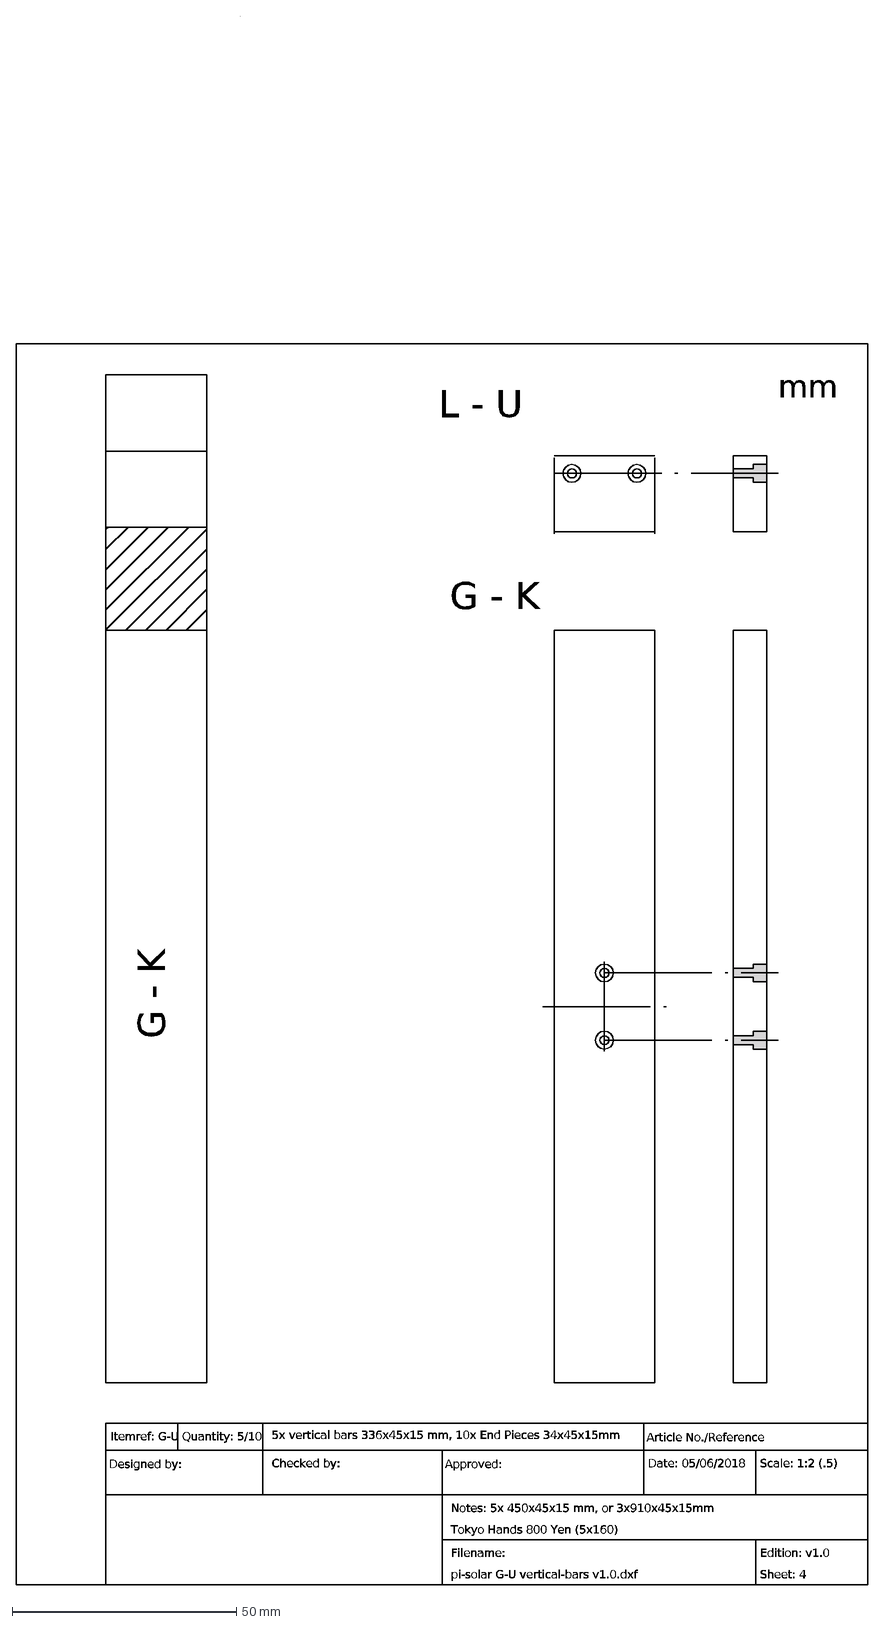
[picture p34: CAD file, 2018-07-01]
cad/pi-solar G-U vertical-bars v1.0.dxf
mm
Itemref: G-U
Quantity: 5/10
5x vertical bars 336x45x15 mm, 10x End Pieces 34x45x15mm
Article No./Reference
Designed by:
Checked by:
Approved:
Filename: pi-solar G-U vertical-bars v1.0.dxf
Date: 05/06/2018
Scale: 1:2 (.5)
Edition: v1.0 Sheet: 4
G - K
L - U
Notes: 5x 450x45x15 mm, or 3x910x45x15mm Tokyo Hands 800 Yen (5x160)

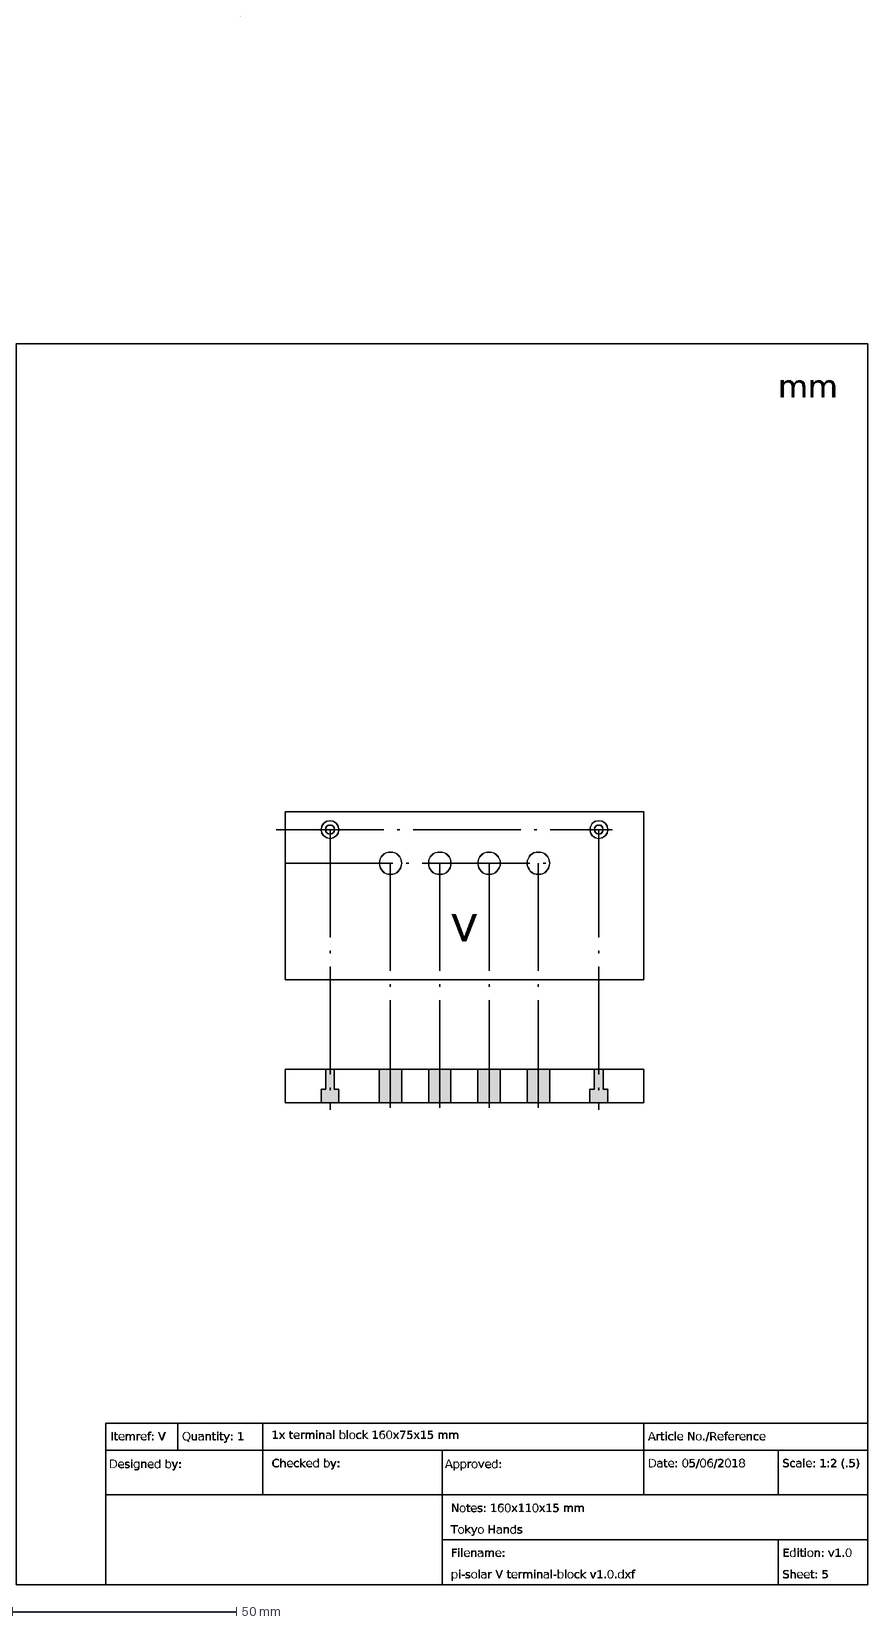
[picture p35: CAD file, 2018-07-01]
cad/pi-solar V terminal-block v1.0.dxf
Itemref: V
Quantity: 1
mm
1x terminal block 160x75x15 mm
Article No./Reference
Designed by:
Checked by:
Approved:
Filename: pi-solar V terminal-block v1.0.dxf
Date: 05/06/2018
Scale: 1:2 (.5)
Edition: v1.0 Sheet: 5
Notes: 160x110x15 mm Tokyo Hands
V

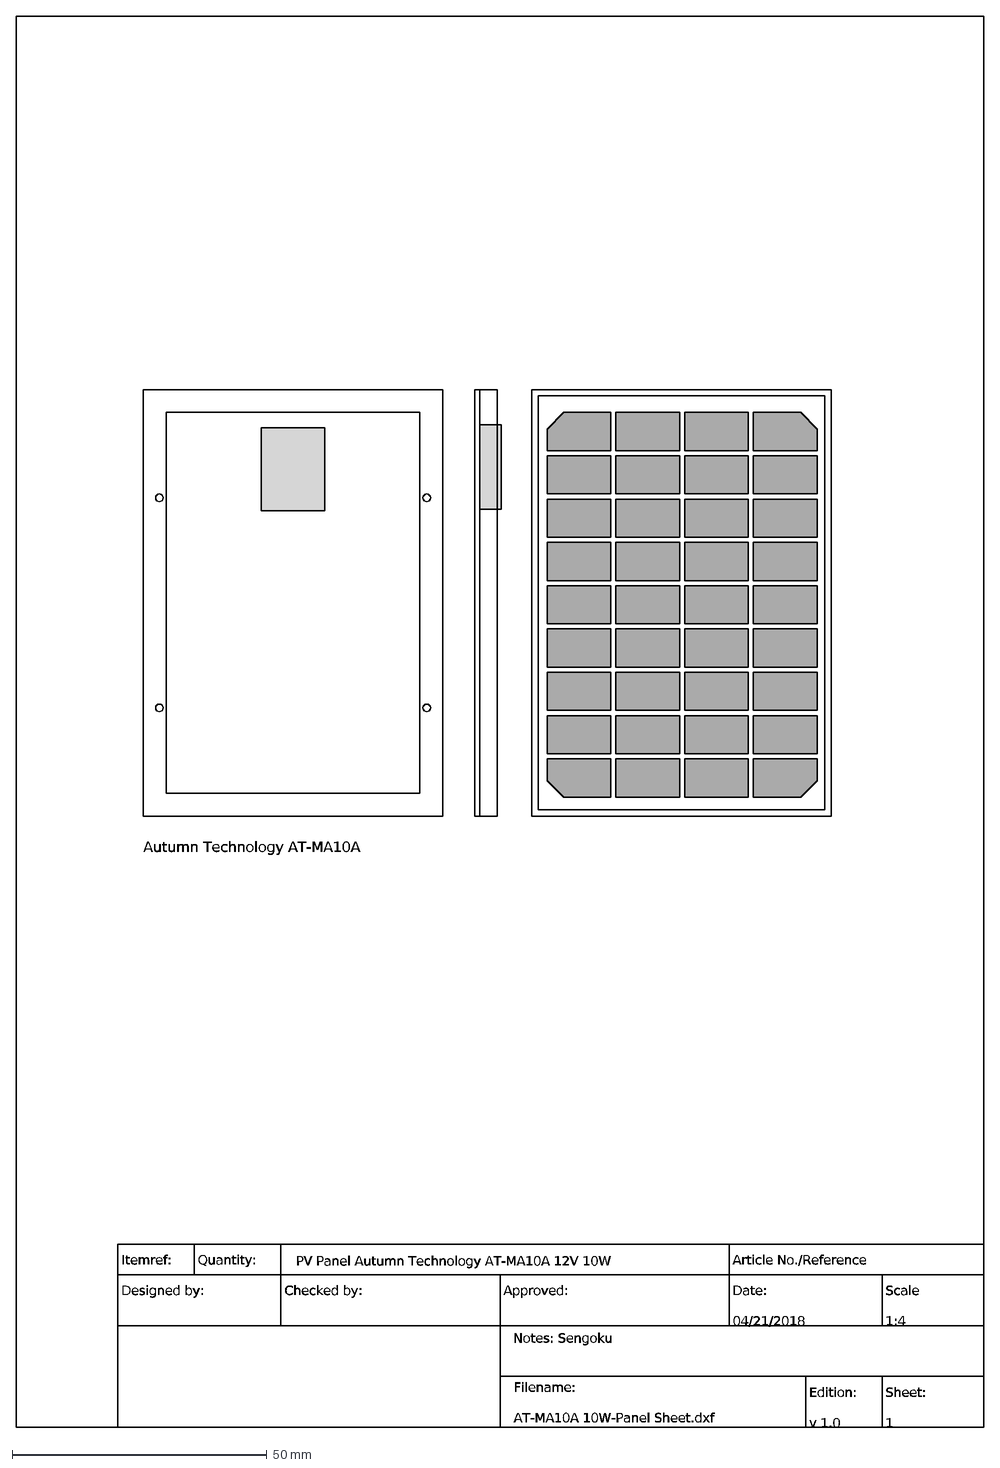
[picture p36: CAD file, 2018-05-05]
cad/AT-MA10A 10W pv panel v10.dxf
Itemref:
Quantity:
PV Panel Autumn Technology AT-MA10A 12V 10W
Article No./Reference
Designed by:
Checked by:
Approved:
Filename: AT-MA10A 10W-Panel Sheet.dxf
Date: 04/21/2018
Scale 1:4
Edition: v 1.0
Sheet: 1
Notes: Sengoku
Autumn Technology AT-MA10A

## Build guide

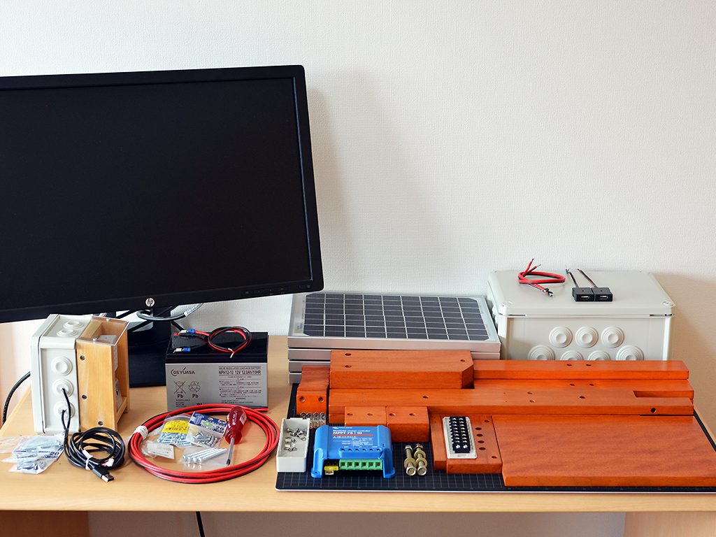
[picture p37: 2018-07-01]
images/pi-solar assembly1.png

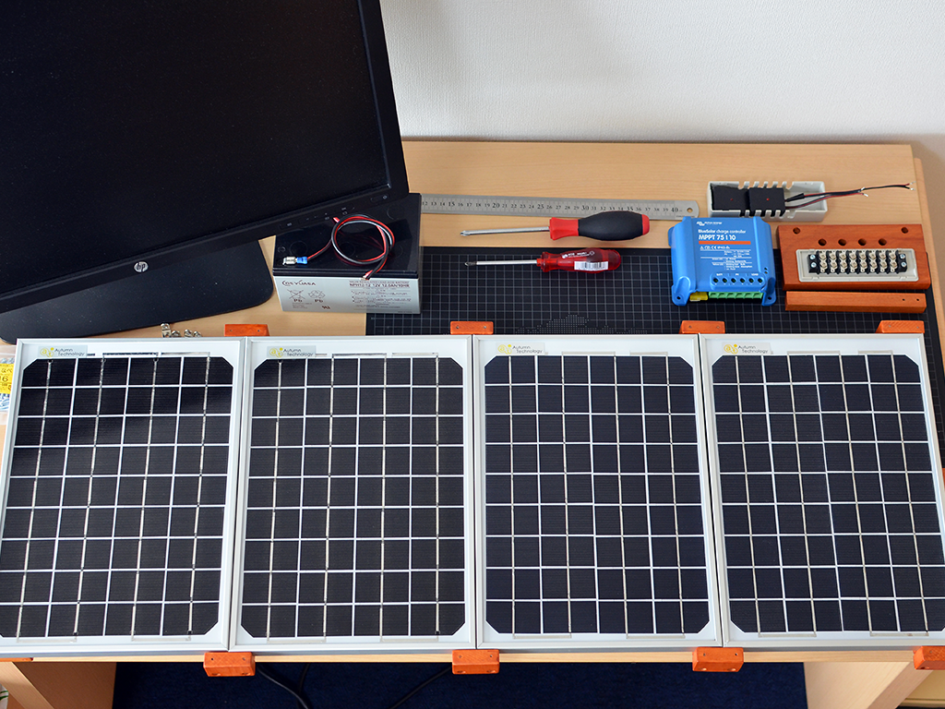
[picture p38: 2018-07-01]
images/pi-solar assembly5.png

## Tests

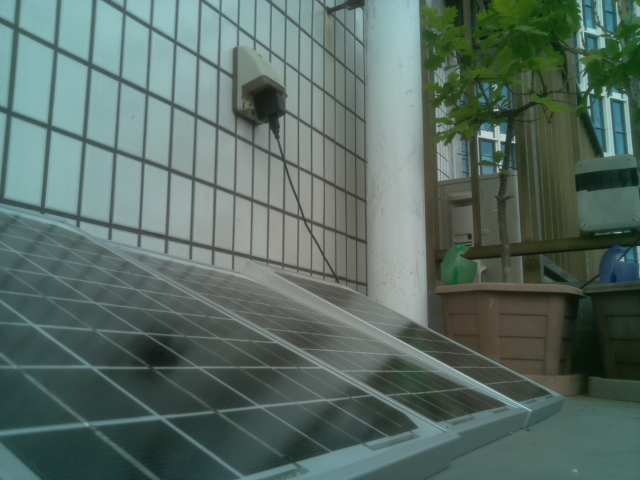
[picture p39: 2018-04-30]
images/pi-solar 3-panel test.jpg

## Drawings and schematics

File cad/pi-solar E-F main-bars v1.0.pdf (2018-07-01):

mm

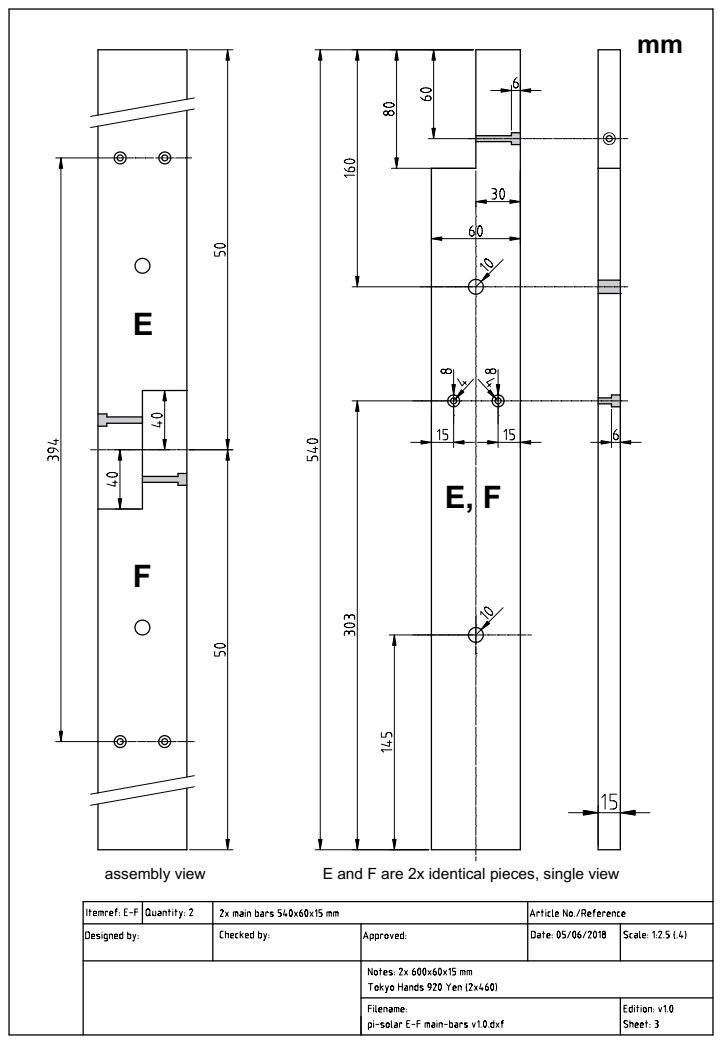
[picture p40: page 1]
assembly view; E and F are 2x identical pieces, single view

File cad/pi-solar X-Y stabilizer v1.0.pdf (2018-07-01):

X

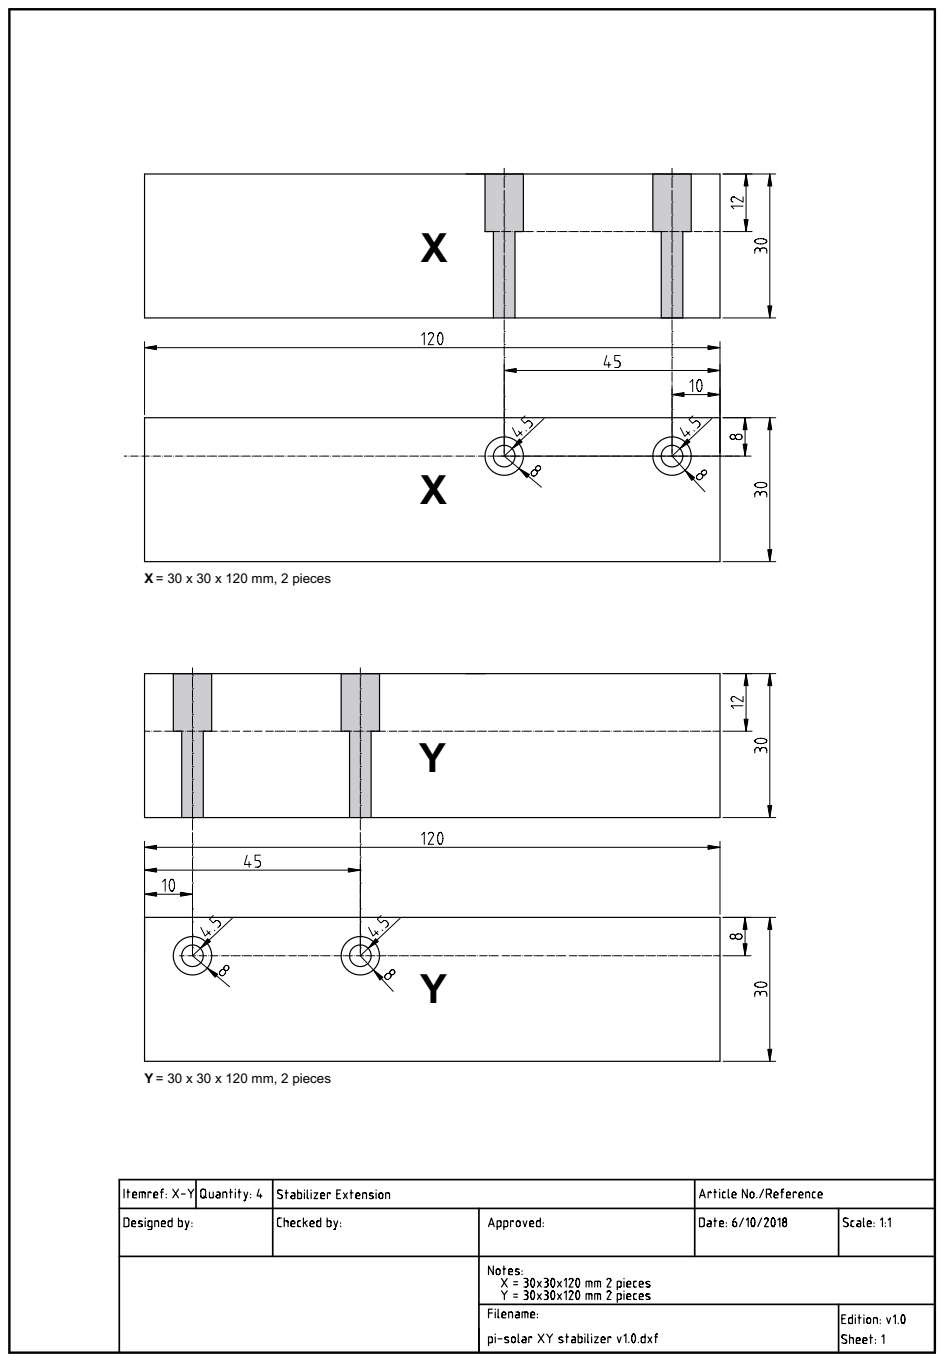
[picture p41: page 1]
= 30 x 30 x 120 mm, 2 pieces

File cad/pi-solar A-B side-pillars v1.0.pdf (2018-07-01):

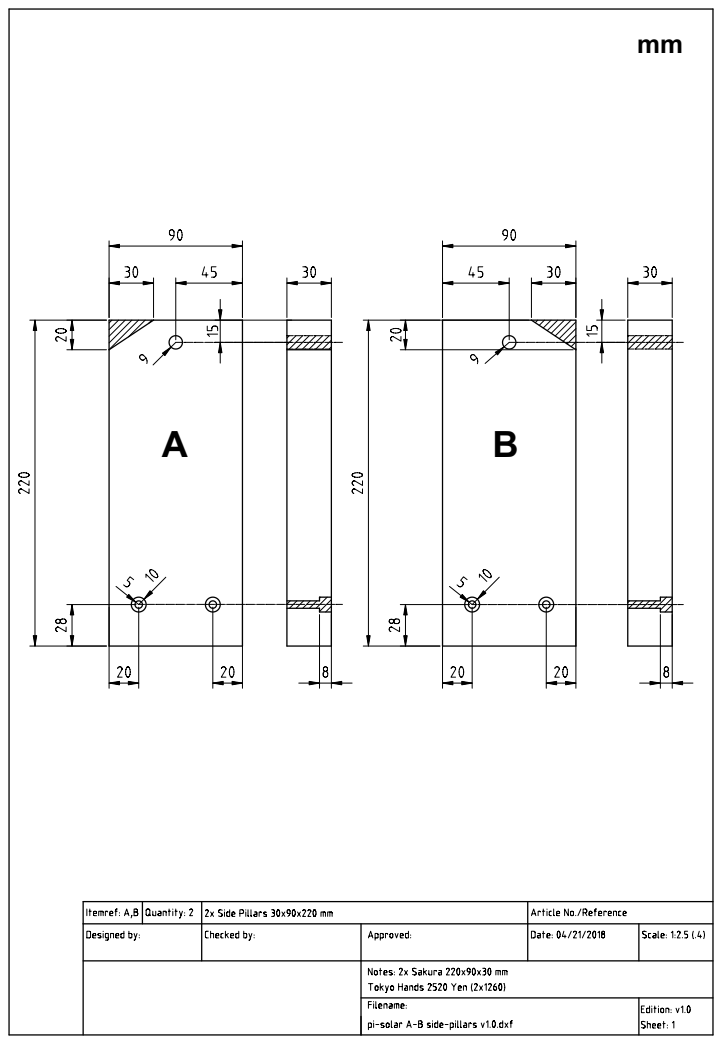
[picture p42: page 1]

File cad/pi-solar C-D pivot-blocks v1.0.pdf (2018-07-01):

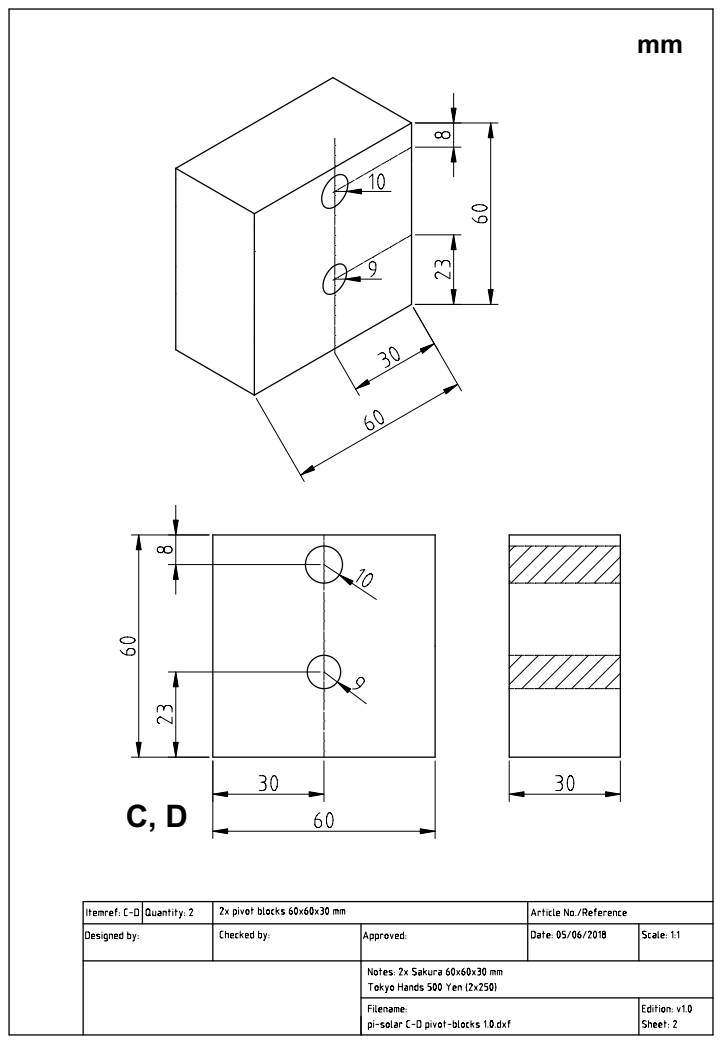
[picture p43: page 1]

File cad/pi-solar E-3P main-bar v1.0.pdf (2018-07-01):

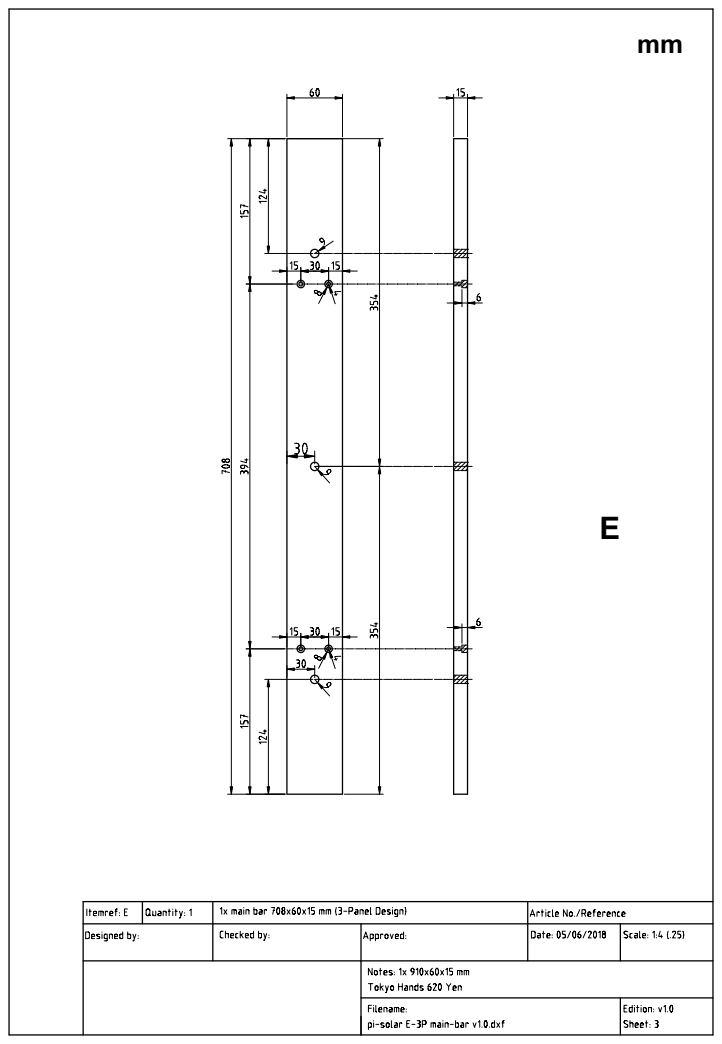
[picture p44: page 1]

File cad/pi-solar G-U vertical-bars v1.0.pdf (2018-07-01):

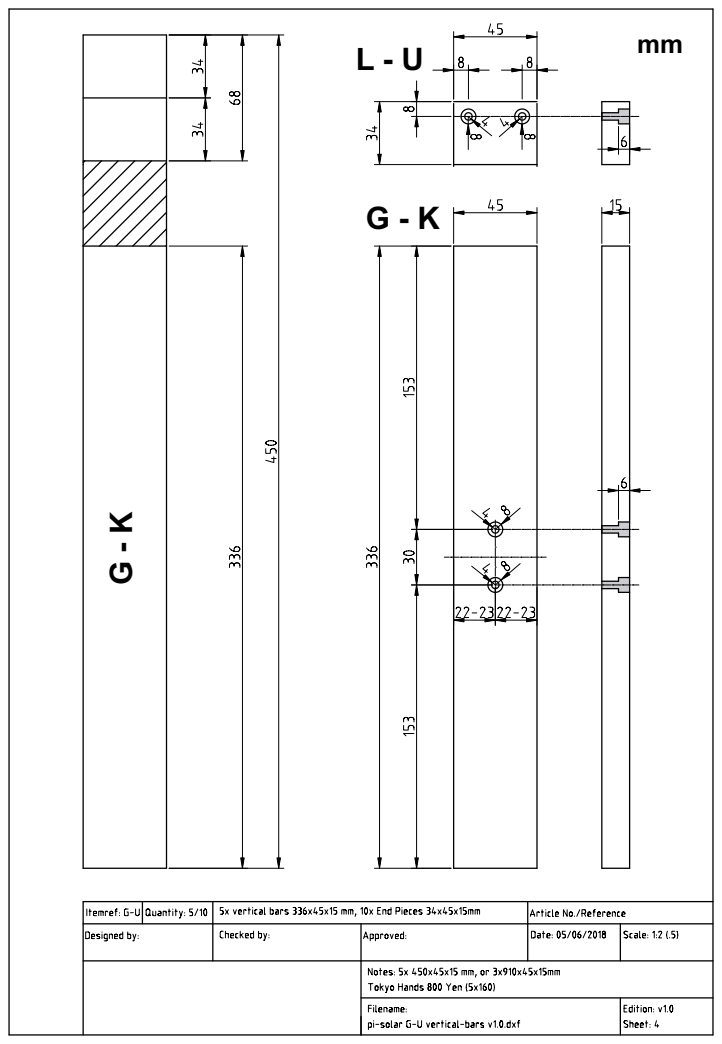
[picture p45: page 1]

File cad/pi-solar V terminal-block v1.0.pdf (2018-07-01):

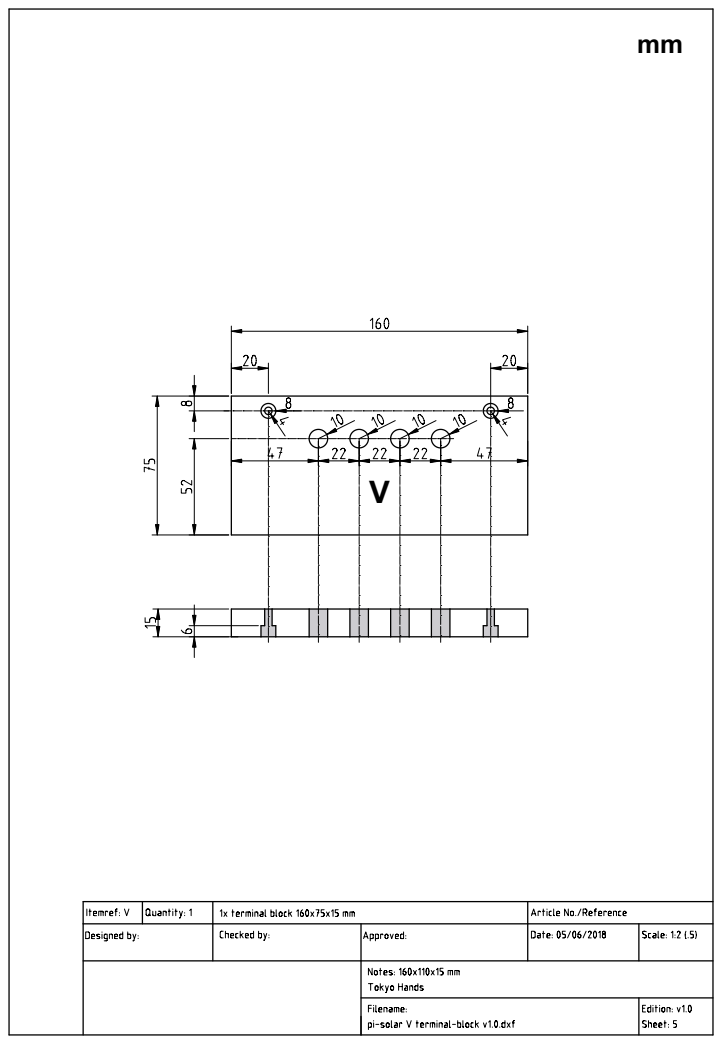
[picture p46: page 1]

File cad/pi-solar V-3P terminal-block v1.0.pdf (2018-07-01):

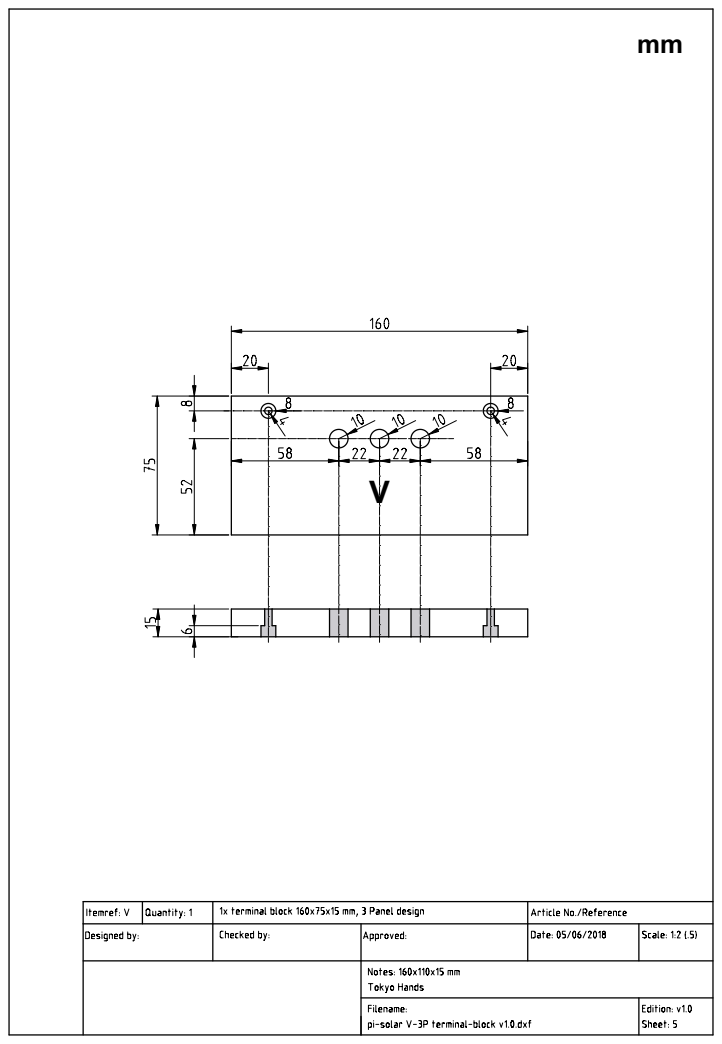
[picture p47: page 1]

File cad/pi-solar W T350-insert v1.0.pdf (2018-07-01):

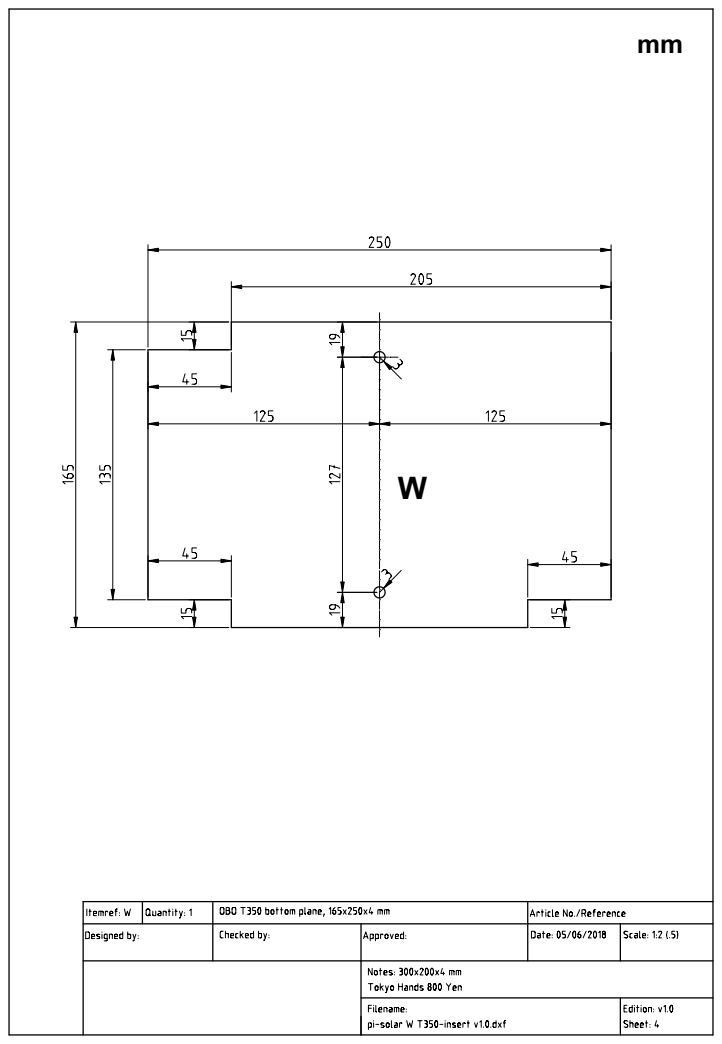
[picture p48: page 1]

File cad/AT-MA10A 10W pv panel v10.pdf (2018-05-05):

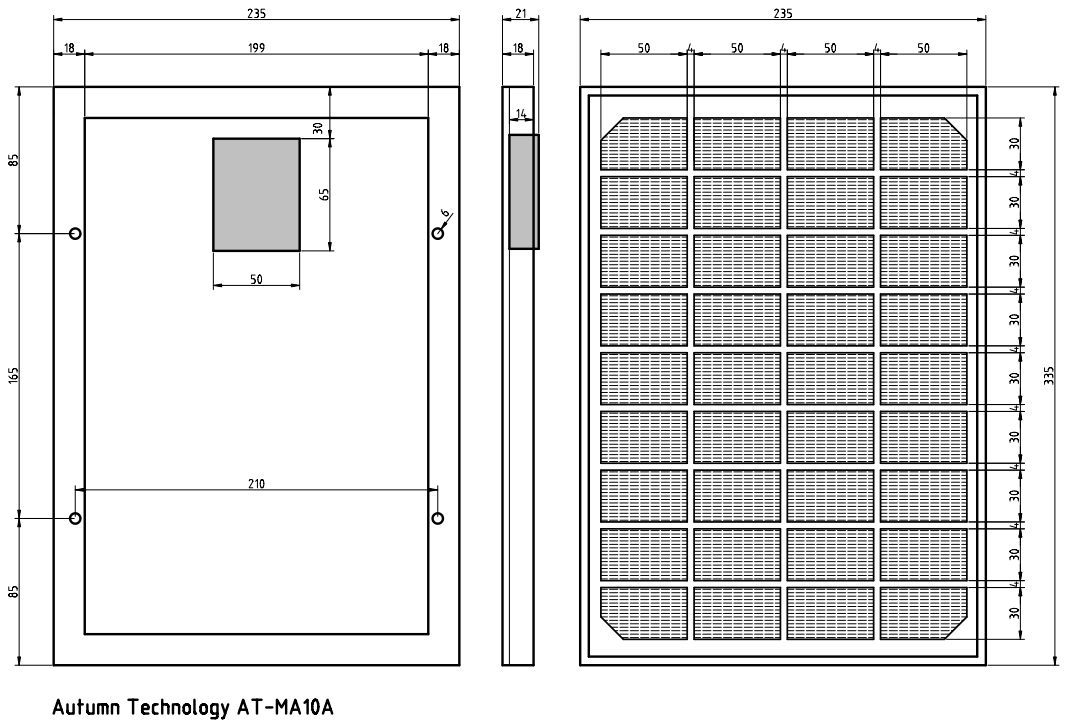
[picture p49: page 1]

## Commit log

2018-04-30 battery graph update
2018-05-01 cable routing
2018-05-05 cad update
    [AT-MA10A 10W pv panel v10.dxf]
2018-12-16 highlight negative in daily power table
